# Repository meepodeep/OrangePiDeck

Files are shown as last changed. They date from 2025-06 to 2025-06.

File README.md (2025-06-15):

# ModuDeck





## A modular cyberdeck that supports multiple SBCS.
  - ### Modules
    - [Exoskeleton](##exoskeleton)
    -   [Compute Modules](##compute) 
        - [Pi 5](###pi-5)
        - [Pi zero 2 w](###pi-zero-2-w)
        - [Lattepanda Mu](###lattepanda-mu)
    - [Battery Modules](##battery)
      - [High Capacity](###2p4s)
      - [Low Capacity](###4s1p)
    - [Keyboard](##keyboard)
    - [Display](##display)
    - [How to assemble modules](##final-assembly)
  - [BOM](#bom) 
## What is the point
I set out to make a modular cyberdeck because I wanted to try to design something that doesnt follow the modern design trends of slimmer and less upgradeable and repairable computers. The modular concept helps alleviate these problems by making use of easily replaceable and upgradeable batteries and SBCs. This also solves the problem of many custom projects being very inconvenient to do maintenance on. For example, some people hotglue everything into place, making the project nearly impossible to work on. In this project, however, every part that you would need to replace is easily replaceable with m3 and m2.5 hardware, securing it in place. 

# Assembly Instructions
- ## Exoskeleton
  - ### Printing
1. Print Both main case peices vertically
2. Print both rear cases flat or vertically if you have elephants foot issues
3. Assemble both sides of each part together using either superglue, plastic welding, or your preferred method of attaching 3d prints.
4. Use m3 hardware to secure the back on once done with wiring exept leave these 3 holes unscrewed, they are for mounting the modules.
5. 
6. 

  - ### Wiring
1. Press fit all of the connectors including, HDMI, XT60, and the magnetic 4pin adafruit connector.
   
   
   
   
  
3. Solder the 12v supply for the xt60 on the battery to the 12v supply on the compute xt60 with 18awg wire.
4. Solder the 5v supply for the xt60 on the battery to the 5v supply on the compute xt60 with 18awg wire.
   
   
   
   
- ## Compute
  - ### Pi 5
 
  
  
1. Print the pi 5 compute model.
2. Assemble the cooler.
3. Solder 28awg wire to the 4 USB pins from the Bottom of the USB 2.0 connector on the set of pins closest to the edge of the board.
4. Remove the casing from the micro HDMI to HDMI adapter.
5. Press the HDMI into the casing.
6. Solder the 5v and gnd connections from the gpio to the + and - terminals onto an xt60 connector using 18awg wire. Press the connector into the 5v part of the module.

  Raspberry-Pi-5-Pinout--1
  
7. Press the 5v Xt60 into the case.
8. Solder the other ends of the wires coming from the USB to the magnetic connector in this order, from left to right, on the pin side. Ground, Data+, Data-, Vcc.
9. Press the Magnetic connector into the case.
10. Screw the pi into the mounting posts with m2.5 hardware.
  - ### Pi zero 2 w



1. Print the Pi Zero Compute model.
2. Assemble the cooler
3. Decase the USB hub.
4. Solder 28awg wire to the pins of the USB port at the end of the hub.
5. Solder the other ends of the wires coming from the USB to the magnetic connector in this order, from left to right, on the pin side. Ground, Data+, Data-, Vcc.
6. Press the Magnetic connector into the case.
7. Solder the 5V and GND connections from the GPIO to the + and - terminals onto an xt60 connector using 18awg wire.
8. Press the connector into the 5V part of the module.

j8header-zero

9. Decase the mini HDMI adapter on the big HDMI side.
10. Press the HDMI into the case, and plug in the mini HDMI.
11. Screw the pi into the mounting posts with m2.5 hardware.
  - ### Lattepanda mu
1. Print the Lattepanda compute module.
2. Assemble the Panda, cooler, and devboard.
3. Desolder the Barrel jack connector
5. Solder 28awg wire to the 4 USB pins on the bottom of the furthest USB connector from the edge of the board on the port that is covered by the case.



6. Solder 18awg wire to the + and - of the barrel jack and solder them to the + and - of an xt60.
7. Press that into the 12V supply port on the module.
8. Solder the other ends of the wires coming from the USB to the magnetic connector in this order, from left to right, on the pin side. Ground, Data+, Data-, Vcc.
9. Desolder the hdmi port and solder 28awg magnet wire or normal wire onto each pin (i know its annoying) and also to the corresponding pins on the board, make these wires long enough to reach the other side of the case.
10. Press the HDMI port into the case.

- ## Battery
  - ### Build
1. Print battery module cover.
2. Print battery module.
  - ### 2p4s
    - Wiring
- # BEFORE DOING THIS MAKE SURE ALL OF THE CELLS ARE AT THE SAME VOLTAGE SO YOU DONT EXPLODE YOU HOUSE!!
1.  Wire 4 pairs of cells in a 1p configuration by spot welding nickel strips in between the cells.
2.  
3.  Wire all 4 of those 1p cells in series into a 2p4s Configuration by spot welding nickel strips, this is the green section of the diagram.
4.  Solder 5 equal-length wires of 22awg to the BMS and to the parts of the battery; these are the purple wires in the diagram.
5. 
6.  Solder a 12awg wire to the - terminal on the BMS.
7.  Solder a 12awg wire to the + terminal on the BMS and to the power switch, solder another 12awg wire to the other side of said switch, and press it into the case.
8.  
9.  Follow the wiring diagram from step 8 in order to complete the battery, then make sure to insulate all of the connections with your preferred method.
10.  Press both XT60s into their respective ports.
11.  Screw on the top using m3 hardware.
  - ### 4s1p
    - Same as 2p4s, but instead of having cell pairs, just use individual cells. 
- ## Keyboard
- 

1. Solder all of the switches onto the PCB.
2. Solder all of the diodes onto the PCB.
4. Solder the Pi Pico onto the bottom of the PCB.
5. Use [QMK Configurator](https://docs.qmk.fm/configurator_step_by_step) to configure and flash the board [here](https://config.qmk.fm/#/rart/rart75hs/LAYOUT_ansi_split_bs)
6.  Desolder the pi picos usb port.
7. Solder a 28awg wire onto each of the usb pads.
8. Solder the other ends of the wires coming from the USB to the magnetic connector in this order, from left to right, on the pin side vcc, Data-, Data+, Ground.
9. Press the magnetic connector into its slot where the compute module clips in.
10. 
11. Slide the keyboard in and screw it down using m3 hardware.
- ## Display
1. Print both screen mount halves and secure them together using ca plastic welding or your preferred adhesive.
2. Use double-sided tape to secure the driver board to the back of the screen on the left side, away from the compute module.
3. Position the screen in the main case and put the scren mount around it aligned with the screw holes.
4. Screw in m3 hardware from the top of the case in all of the holes.
5. Plug the HDMI coming from the compute module bay into the display board.
6. Use 18awg wire to the 12V XT60 from the battery module bay to the power pads on the driver board after desoldering the barrel plug.
- ## Final Assembly
1. Slot the compute module into the left of the cyberdeck making sure all of the connectors line up.
2. Use 2 m3 bolts to secure the module in place.
3. 
4. Slot the battery in, turned off, into the slot on the right, making sure all of the connectors line up.
5. Screw in one m3 bolt to secure it in place
6. 

# BOM

| Item |	Quantity |	Total price+Shipping | Use In project	| Item Source
| --- | --- | --- | --- |--- |
| General |||||			
| Display |	x1 |	$64.19 |	displays | https://www.ebay.com/itm/145841358470? |
| m3 hardware kit |	x1	| $7.99|	Mount most things	| https://www.amazon.com/Hincell-540pcs-Button-Washers-Stainless/dp/B0D1CV8V9Y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|
|m2.5 4mm |	x1 |	$1.86 |	mount the pis if you use them |	https://www.aliexpress.us/item/3256805692588351.html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|
|18awg wire	| x1 |	$13.76 | most wiring |	https://www.amazon.com/Nilight-Electrical-Conductor-Extension-Amplifier/dp/B0CYZPW42Q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 |
|28awg wire	| x1 |	$7.99 |	Usb wiring |	https://www.amazon.com/Fermerry-Stranded-Silicone-Cables-Electrical/dp/B089CR4SDM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 |
|12awg wire |	x1 |	$3.94 |	Battery wires |	https://www.aliexpress.us/item/3256807129117447.html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|
|Filament	| x1 |	$20 |	be every printed part |	Idk wherever you get filament |
|xt60s	| x1 |	$8.99 |	be every printed part |	[amazon](https://www.amazon.com/Amass-Bullet-Connector-Upgrated-Sheath/dp/B074PN6N4K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) |
|Magnetic Connectors| x1 | $$3.67 | Connect usb |https://www.aliexpress.us/item/3256805098127227.html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|
|Nickel strip| x1| $5.69 | build batteries| https://www.amazon.com/MECCANIXITY-Nickel-Battery-Soldering-Welding/dp/B0CVXLLGCQ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|
|Total|| $138.08 |||
||||||
|Keyboard Parts	| | | | |	
|Pi pico |	x1 |	$4 |	drive the keyboard | https://www.adafruit.com/product/4864 |
|Keyboard pcb	| x5 |	$35.47 |	Be a keyboard PCB |	PCBWAY |
|Gateron Red	| x100	| $34.40 |	Be switches |	https://www.aliexpress.us/item/3256805905674117 |
|Keycaps |	x80 |	$14.16 |	Be keycaps |	https://www.aliexpress.us/item/3256807292808339.html? |
|Shipping |	$6.99	| | | |
|Total | |$95 | | |		
||||||
|Battery Module 2p4s |||||				
|DC-DC converter |	x2 |	$25.60 |	Convert the battery voltage to 12v/5v |	https://www.dfrobot.com/product-2599.html |
|18650s | x8 |	$29.28 |	be batteries |	https://www.18650batterystore.com/products/samsung-25r-18650?variant=37119890063511 |
|Bms |	x1 |	$1.75 |	be a bms for the batteries |	https://www.aliexpress.us/item/ |
|RA11131121 |	x1 |	$0.69 |	power switch |	https://www.mouser.com/ProductDetail/E-Switch/RA11131121?qs=QtyuwXswaQhes8SRTBHYHQ%3D%3D&mgh=1&gQT=1 |
|373 |	x1 |	$0.95 |	charger |	https://www.mouser.com/ProductDetail/Adafruit/373?qs=GURawfaeGuDDC%2FyE6Usrdw%3D%3D |
|Total| |	$58.27 | | |	
|Battery Module 4s1p |||||	
|DC-DC converter |	x2 |	$25.60 |	Convert the battery voltage to 12v/5v |	https://www.dfrobot.com/product-2599.html |
|18650s | 	x4 |	$18.59 |	be batteries |	https://www.18650batterystore.com/products/samsung-25r-18650?variant=37119890063511 |
|Bms |	x1 |	$1.75 |	be a bms for the batteries |	https://www.aliexpress.us/item/ |
|RA11131121 |	x1 |	$3.26 |	power switch |	https://www.aliexpress.us/item/3256808591861621.html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 |
|Total | | $49.20 |	| |	
||||||
|Pi zero 2 w compute | | | | |
|pi zero 2 w	| x1 |	$23.00 |	Main computer |	https://www.adafruit.com/product/5291 |
|mini hdmi to hdmi adapter |	x1 |	$6.99 |	adapt the HDMI |	https://www.amazon.com/Micro-Adapter-Female-Support-Raspberry/dp/B09HS74STL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 |
| USB hub and pi cooloer	| x1 |	$9.99 |	Cool the pi and breakout usb |	https://www.amazon.com/Raspberry-iUniker-Aluminum-Passive-Adapter/dp/B09XK36QNB/140-2177712-4060064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 |
|Total |	| $39.98 |	| | |	
||||||	
|Pi 5 Compute | | | | |
|Pi 5 8gb |	x1 |	$96.98 |	main computer |	https://www.pishop.us/product/raspberry-pi-5-8gb/?searchid=0&search_query=pi+5|
|Micro HDMI to Standard HDMI |	x1 |	$4.25 |	hdmi adapter |	https://www.pishop.us/product/micro-hdmi-to-standard-hdmi-adapter-white/|
|Cooler	| x1 |	$8.95 |	cool the pi |	https://www.pishop.us/product/dedicated-all-in-one-aluminum-cooler-for-raspberry-pi-5-pwm/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|
|Total | | $110.18 | | |	
||||||
|Lattepanda Mu Compute| | | | |	
|Lattepanda Mu with lite carrier and active cooler |	x1 |	$220.00 |	main computer |	https://www.dfrobot.com/kit-004.html|
|Total| |	$220.00| | |

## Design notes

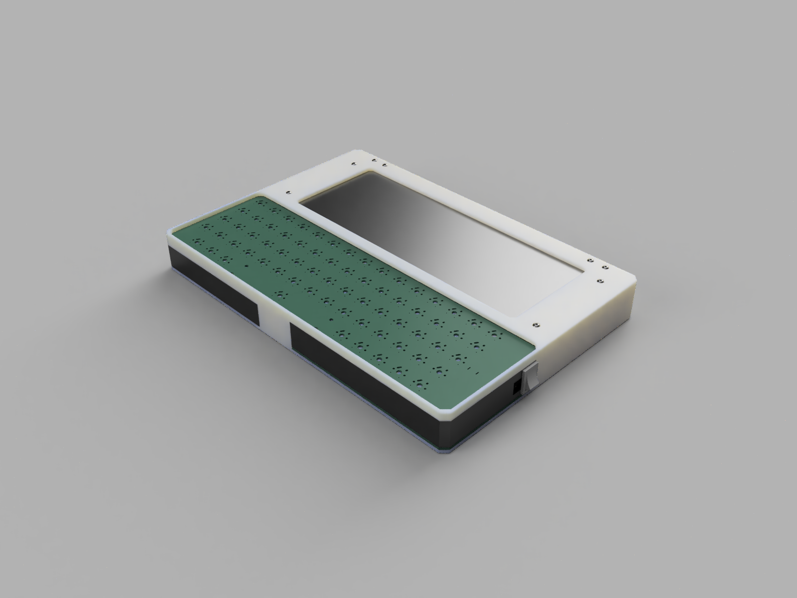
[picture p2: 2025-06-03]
OrangeDeck_Keyboard_2025-Jun-01_12-19-17AM-000_CustomizedView39958334056.png

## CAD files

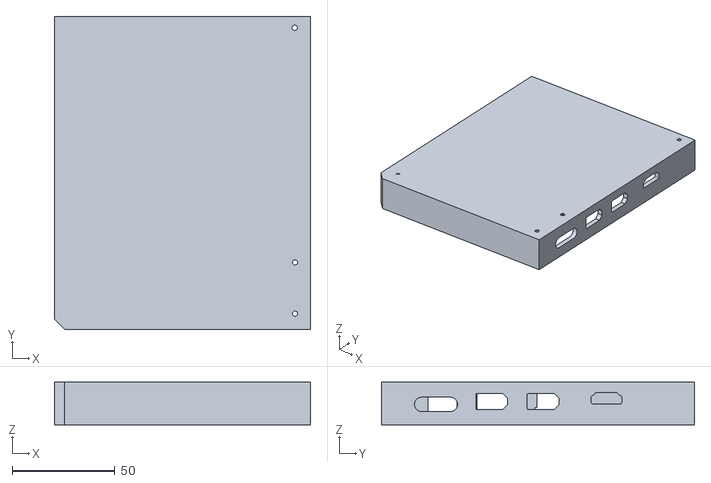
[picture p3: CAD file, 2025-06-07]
Panda Compute Main.stl
124.8 x 152.4 x 20.8

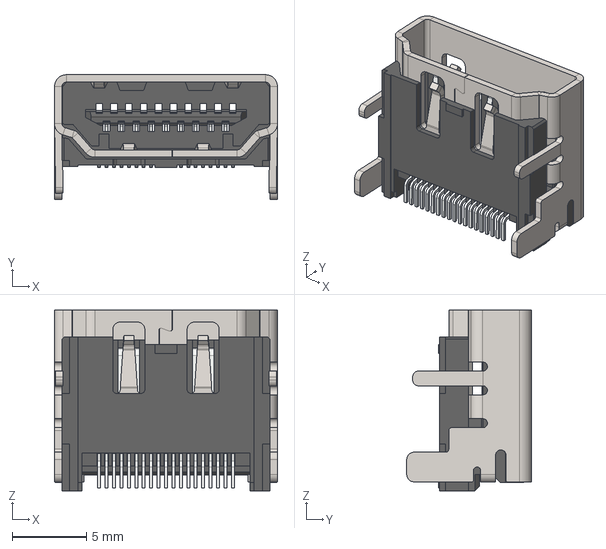
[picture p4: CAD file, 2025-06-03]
Component Steps/molex.STEP
15.0 x 8.38 x 12.1 mm

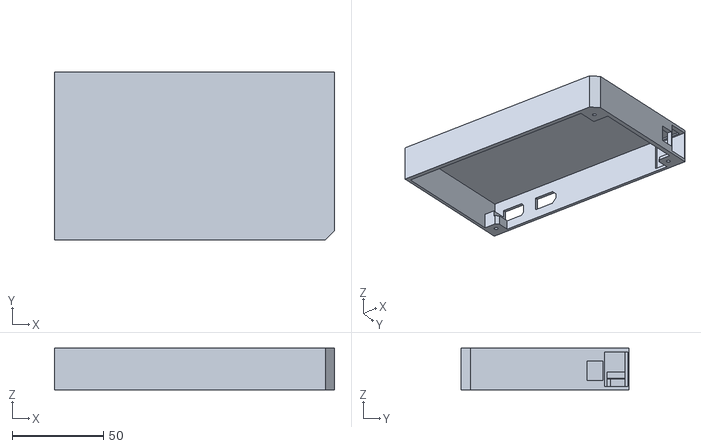
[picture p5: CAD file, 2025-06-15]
Final Print files/Battery/Battery module.stl
153.6 x 92.0 x 22.9

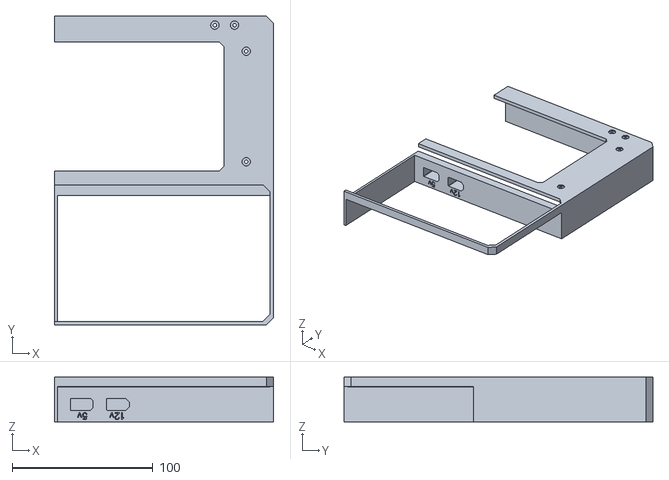
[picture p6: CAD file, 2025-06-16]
Final Print files/Exoskeleton/Case Right.stl
155.8 x 219.6 x 32.0

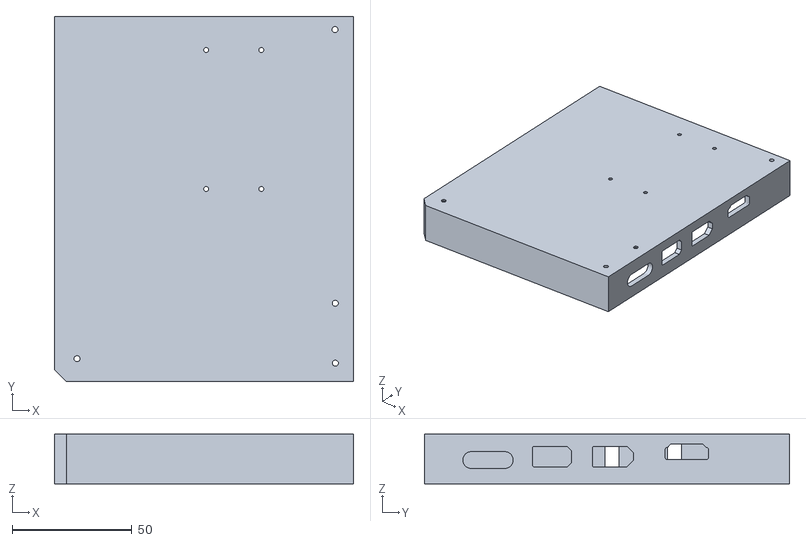
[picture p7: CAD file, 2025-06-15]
Final Print files/Pi compute/Rpi zero compute.stl
124.8 x 152.4 x 20.8

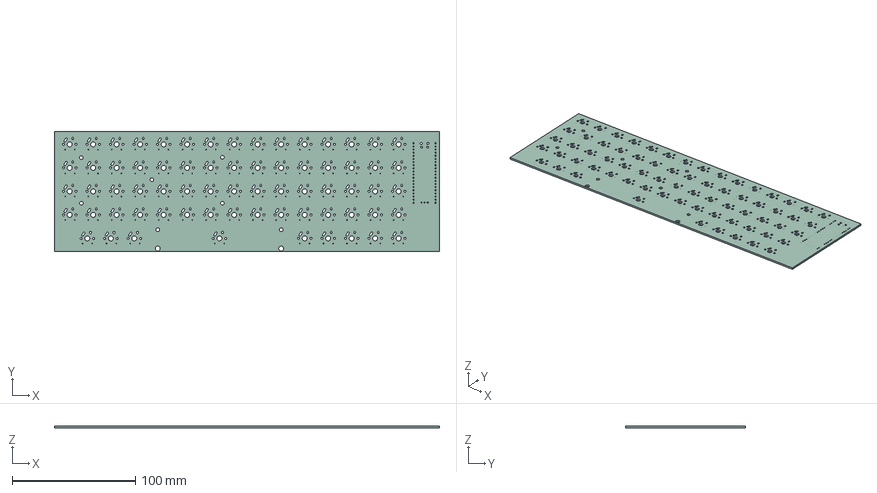
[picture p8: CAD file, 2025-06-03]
ModuDeck Keyboard/ModuDeck Keyboard.step
312.1 x 97.1 x 1.51 mm

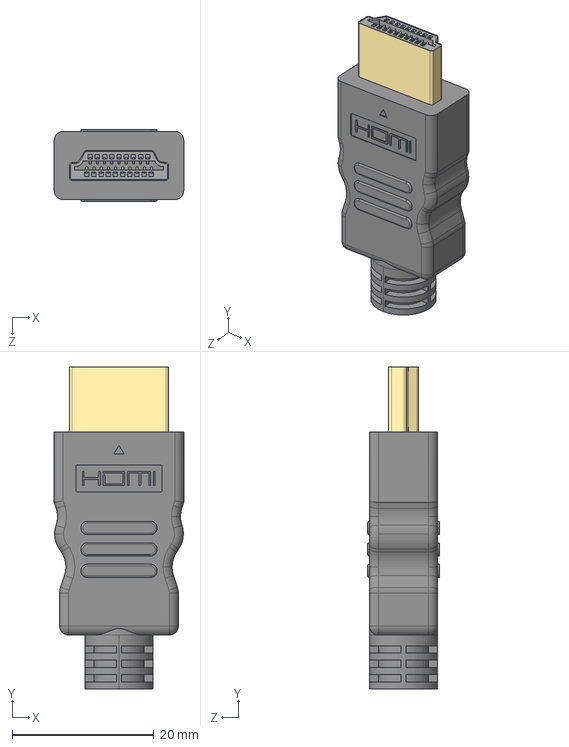
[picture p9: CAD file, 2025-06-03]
Component Steps/HDMI Male V2.STEP
18.3 x 45.5 x 10.2 mm

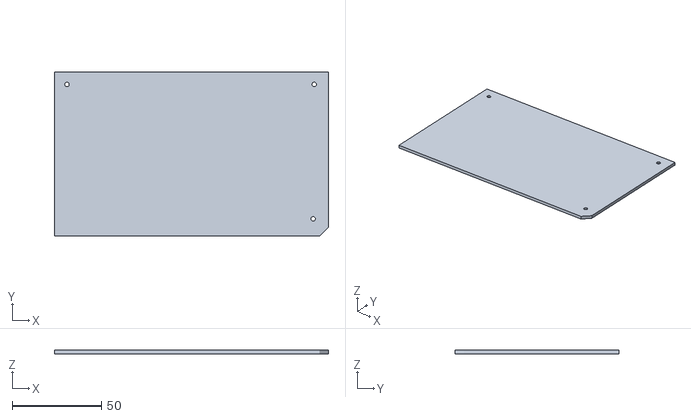
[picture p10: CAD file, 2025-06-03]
Final Print files/Battery/Battery module cover.stl
153.6 x 92.0 x 1.99

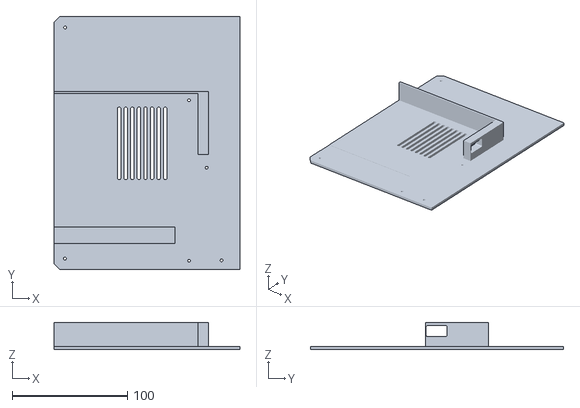
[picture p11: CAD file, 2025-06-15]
Final Print files/Exoskeleton/Back Case left.stl
161.3 x 219.6 x 23.8

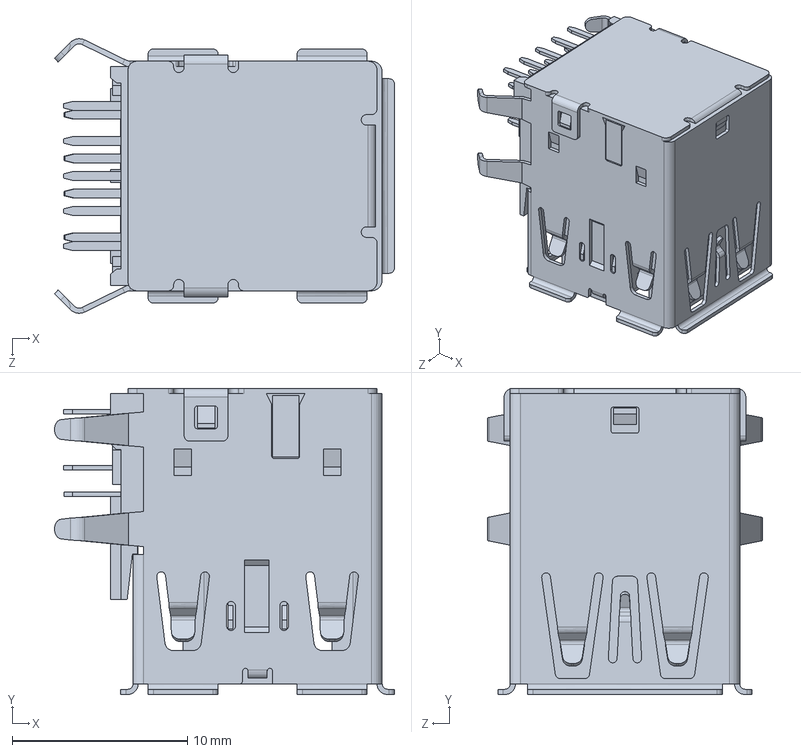
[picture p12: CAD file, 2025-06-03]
ModuDeck Keyboard/usb3x2.SLDPRT
19.4 x 17.5 x 15.7 mm

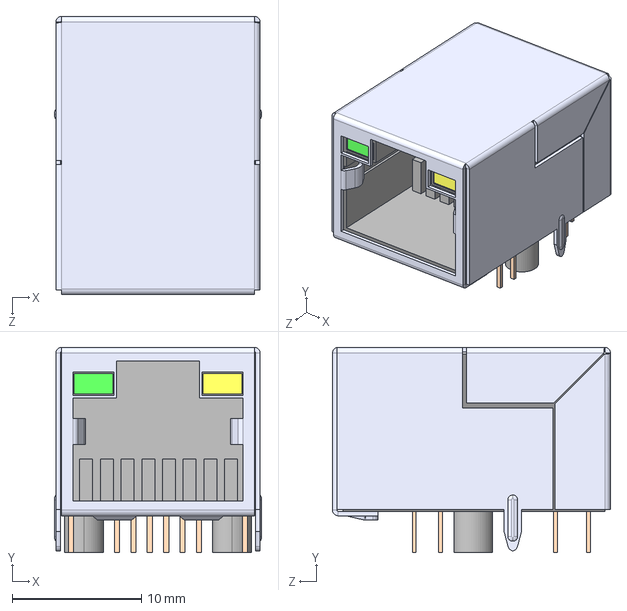
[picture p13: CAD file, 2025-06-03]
Component Steps/RJ45_10P_TJ3009.STEP
16.0 x 15.9 x 21.5 mm

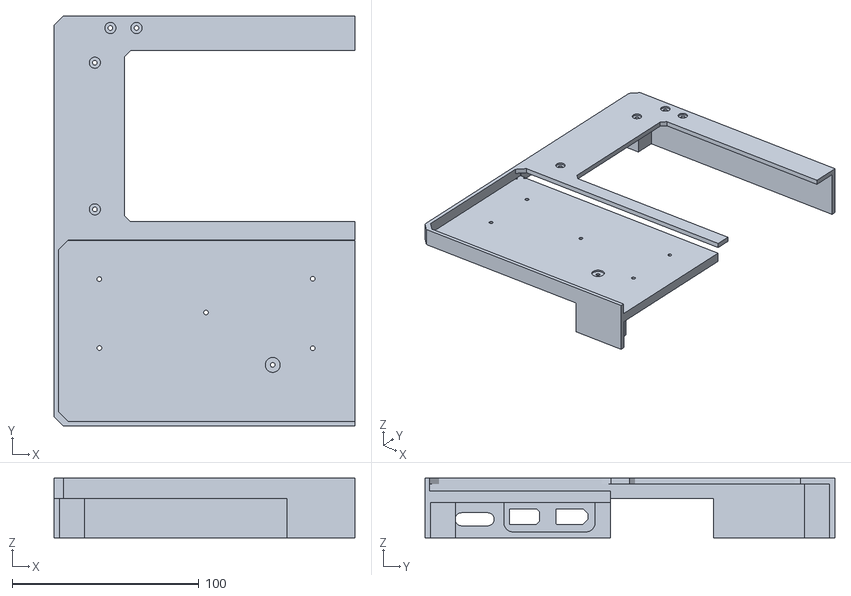
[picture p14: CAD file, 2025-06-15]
Final Print files/Exoskeleton/Case left.stl
161.3 x 219.6 x 32.0

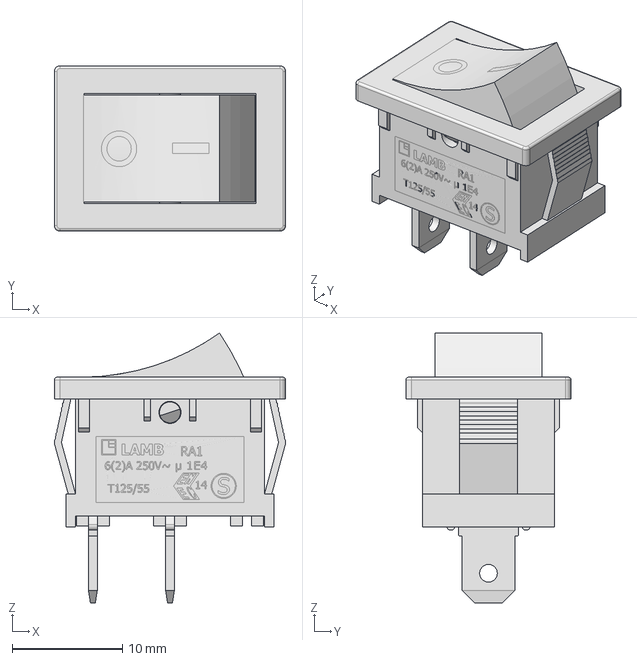
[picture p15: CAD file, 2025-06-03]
Component Steps/RA1113xxx1.stp
21.0 x 15.0 x 24.5 mm

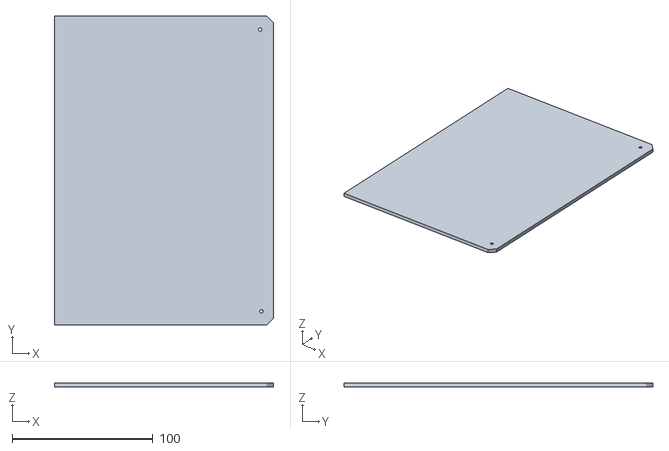
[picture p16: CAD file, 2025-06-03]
Final Print files/Exoskeleton/Back Case right.stl
155.8 x 219.6 x 3.00

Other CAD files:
Final Print files/Compute Module Template.step
Final Print files/Pi compute/Pi 5 Compute.stl
Component Steps/XT60_Hembra.STEP
Final Print files/Exoskeleton/Screen Mount other half.stl
Component Steps/Case.3mf
Component Steps/DC Power Jack 5.5mm x 2.1mm.STEP
Component Steps/Screen Mount.3mf
Component Steps/USB Type C Port (SMD Type).STEP
Component Steps/connecteurmagnetique.STEP
Final Print files/Exoskeleton/Back case.stl
Final Print files/Exoskeleton/Case.stl
Final Print files/Exoskeleton/Screen Mount.stl

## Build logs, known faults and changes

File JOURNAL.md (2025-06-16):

---
title: "ModuDeck"
author: "Meepodeep"
description: "Cyberdeck but Modular!"
created_at: "2025-05-22"
---
# Total time spent ~52 hours, (I think I forgot to log a few days and I dont remember what days 😢)
# 5/22/25: Starting project

I started and finished the keyboard pcb design!





**Total time spent: 9h**
# 5/25/25: Worked on case.

Started making the case for the cyberdeck and also researched carrier board options. 



**Total time spent: 6h**

# 5/26/25: Worked on case.

Started designing mounts for the components in the case. 



**Total time spent: 2h**

# 5/27/25: Tried to make some sort of BOM.

I have been looking for parts for a while now. After making the Bom realized I'm going to have to sacrifice some features to stay in budget. I might try to integrate an old keyboard that I have instead of using the custom PCB I designed. Hopefully I can keep this thing under budget. 



**Total time spent: 4h**
# 5/28/25: Changed the concept entirely!

In order to stay under budget, I decided to make a modular system with you being able to hotswap SBC and battery modules in and out of the deck. I mostly just did a lot of CAD.



**Total time spent: 9h**
# 6/2/25: Finished some modules!

I finished the battery module, and i also finished the lattepanda mu module. I started work on the rpi zero module and i added some visual flairs.





**Total time spent: 3h**

# 6/3/25: Finished designing!

Today, I started doing alot of finalization steps. I made the pi 5 module, I also have a module template for both the battery and compute now. And I did alot of fine tuning of the mounts and printability of the design. After all of that, I went back and changed the keyboard to use a pi pico to make my life easier when soldering and setting up firmware. The most annoying part of today was just doing all the little touches to make this thing actually be reasonable for others and myself to assemble in real life like adding screw posts and splitting parts in half. 





**Total time spent: 7h**

# 6/4/25: started docs!

currently working on making instructions to build the project.

Check Readme.md for the progress

**Total time spent: 1h**

# 6/6/25: Worked on docs!

Wrote the assembly guide for the compute modules, batteries, and case. 

**Total time spent: 5h**

# 6/7/25: Worked on documentation and bom for every module 😢

Today I did a lot of writing. I wrote the assembly instructions for the remaining parts of the build, and i also wrote the bom with it being seperated to have individual costs for each module. 

**Total time spent: 5h**

# 6/11/25: edited some bits on the bom bc the prices changed. 

The display price changed due to going off sale, and I also ordered all the parts.

**Total time spent: 2h**

# 6/12/25: Edited the pi zero compute module

When I was test fitting something was off (i dont remember i forgot to log this day this is retroactive looking at commits) so I edited the 3d model.

**Total time spent 1h**

# 6/13/25: Edited ports.

Every port on the model was the wrong size, so nothing fit. I changed all of them to fit with measurements from the components that arrived today. Then I re printed and rebuilt it again. 

**Total time spent 5h**

# 6/14/2025 I HATE RASPBERRY PI OS!!!!

Ok so today I was just messing with linux to try to get a pi zero to do anything useful on the desktop. I have realized that this will be a command line machine until I can build a more useful compute module. I also started building stuff with the new HDMI slots and mounted the ports. 

**Total time spent 6h**

#6/15/2025 I updated all the xt60 mounts to fit the connectors.

As the title says i edited the 3d model to fit the xt60s better.

**total time spent 2h**

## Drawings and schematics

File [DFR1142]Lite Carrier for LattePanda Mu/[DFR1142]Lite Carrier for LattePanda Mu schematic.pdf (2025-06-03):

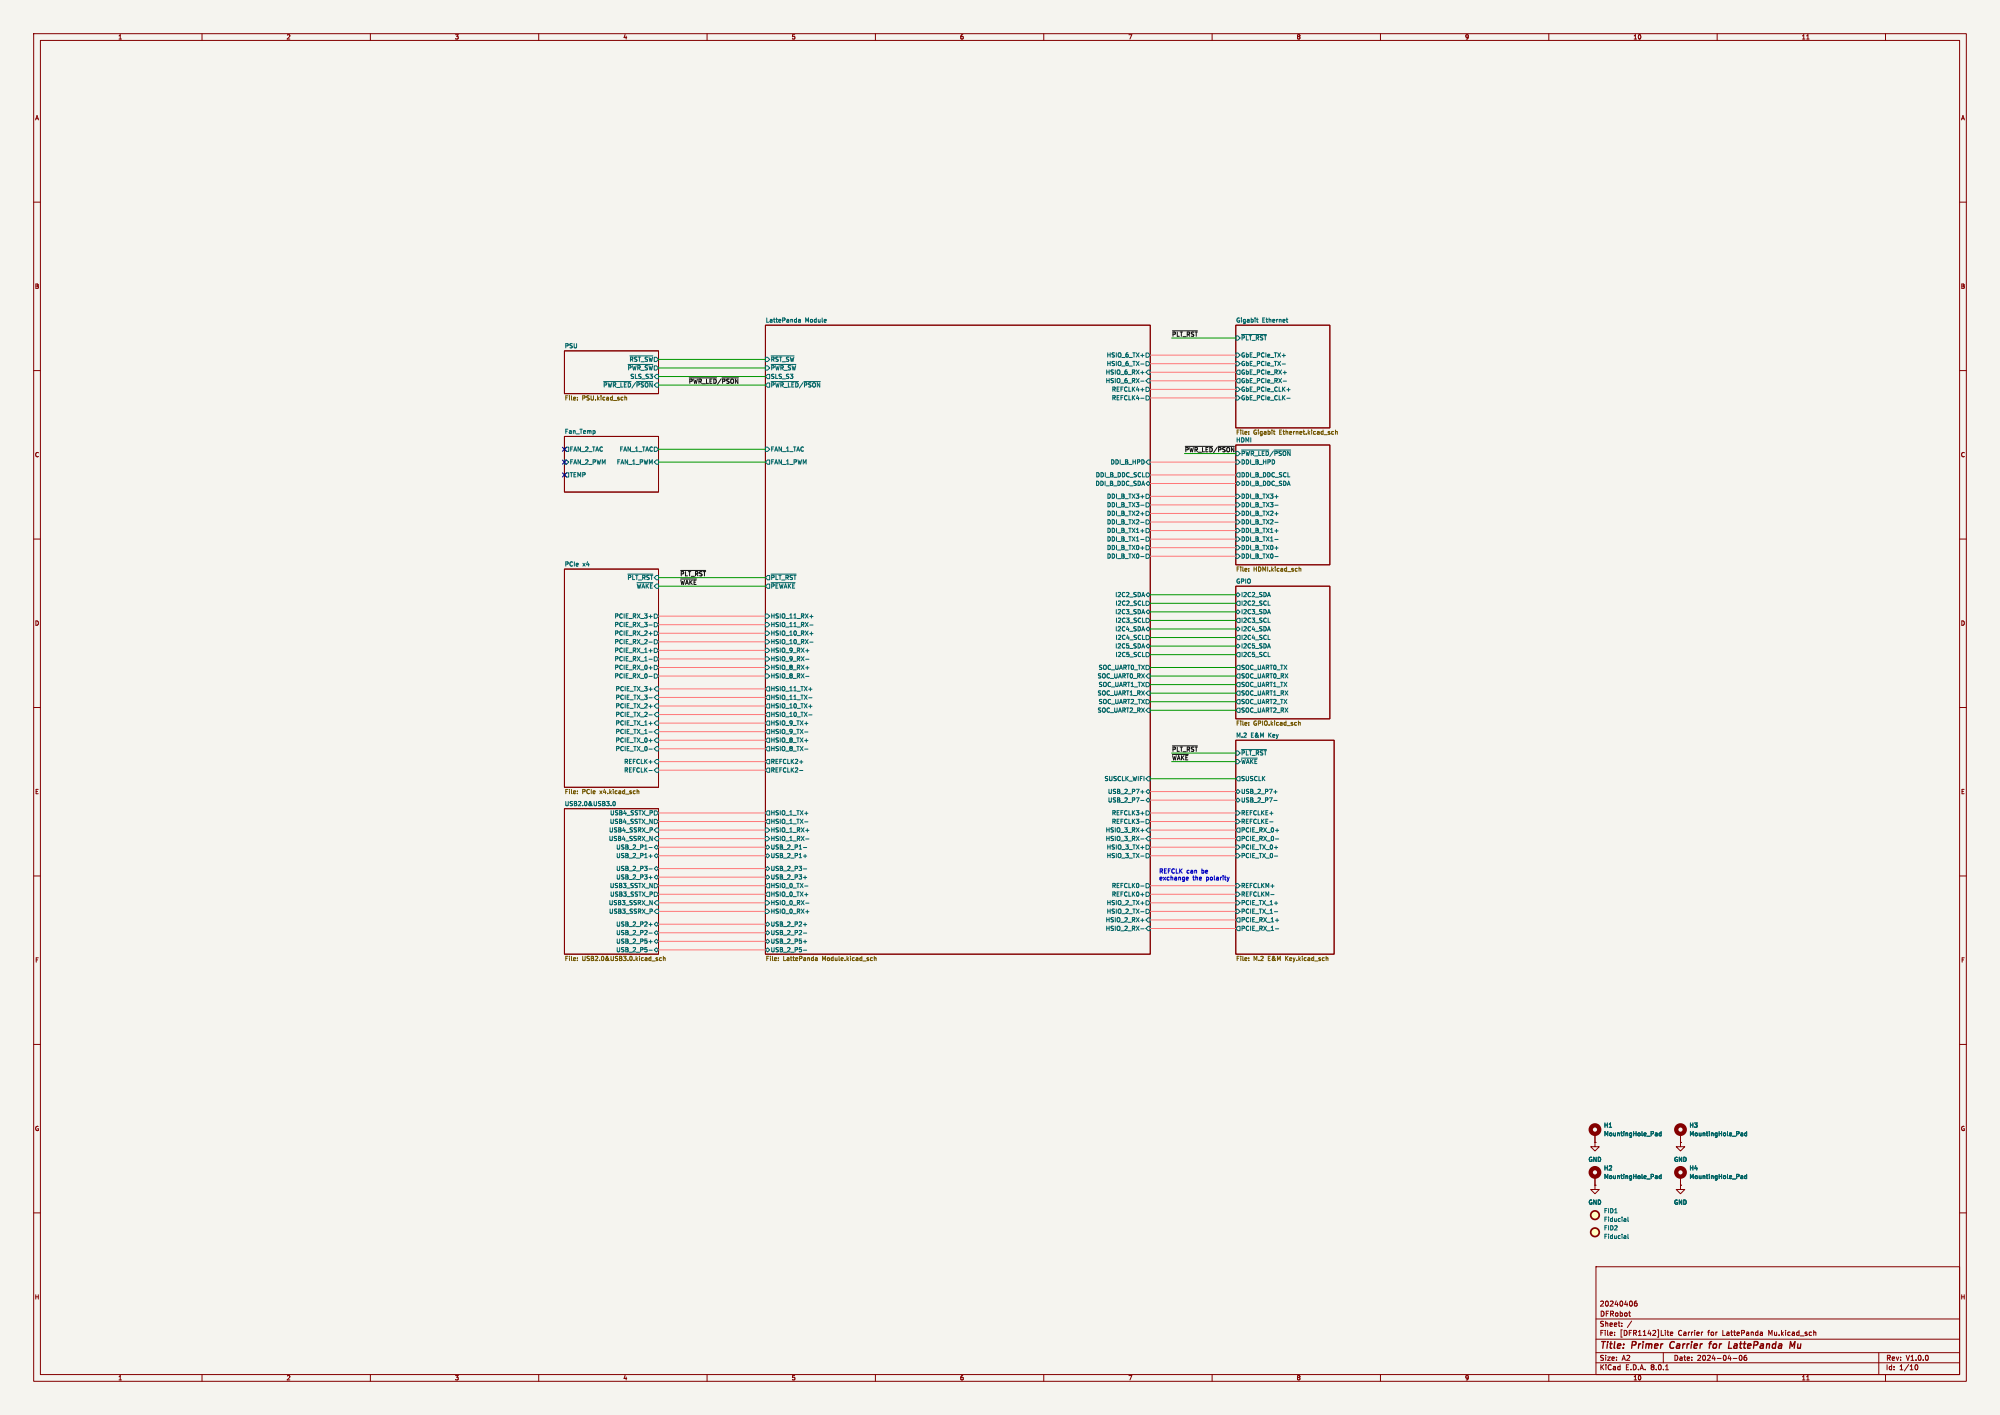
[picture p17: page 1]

Gigabit Ethernet File: Gigabit Ethernet.kicad_sch FAN_1_TAC
File: PSU.kicad_sch PCIE_RX_3- PCIE_RX_2- PCIE_RX_3+ PCIE_RX_0- PCIE_RX_1- PCIE_RX_1+ PCIE_RX_0+ PCIE_RX_2+
~{WAKE} PCIe x4 File: PCIe x4.kicad_sch USB3_SSRX_P USB3_SSRX_N
~{PLT_RST} REFCLK- REFCLK+ PCIE_TX_3- PCIE_TX_3+ PCIE_TX_2- PCIE_TX_0+ PCIE_TX_2+ PCIE_TX_1- PCIE_TX_0- PCIE_TX_1+

~{PLT_RST}
~{PWR_LED}/~{PSON} HDMI File: HDMI.kicad_sch GbE_PCIe_CLK- GbE_PCIe_RX+ GbE_PCIe_RX- GbE_PCIe_TX- GbE_PCIe_TX+ GbE_PCIe_CLK+

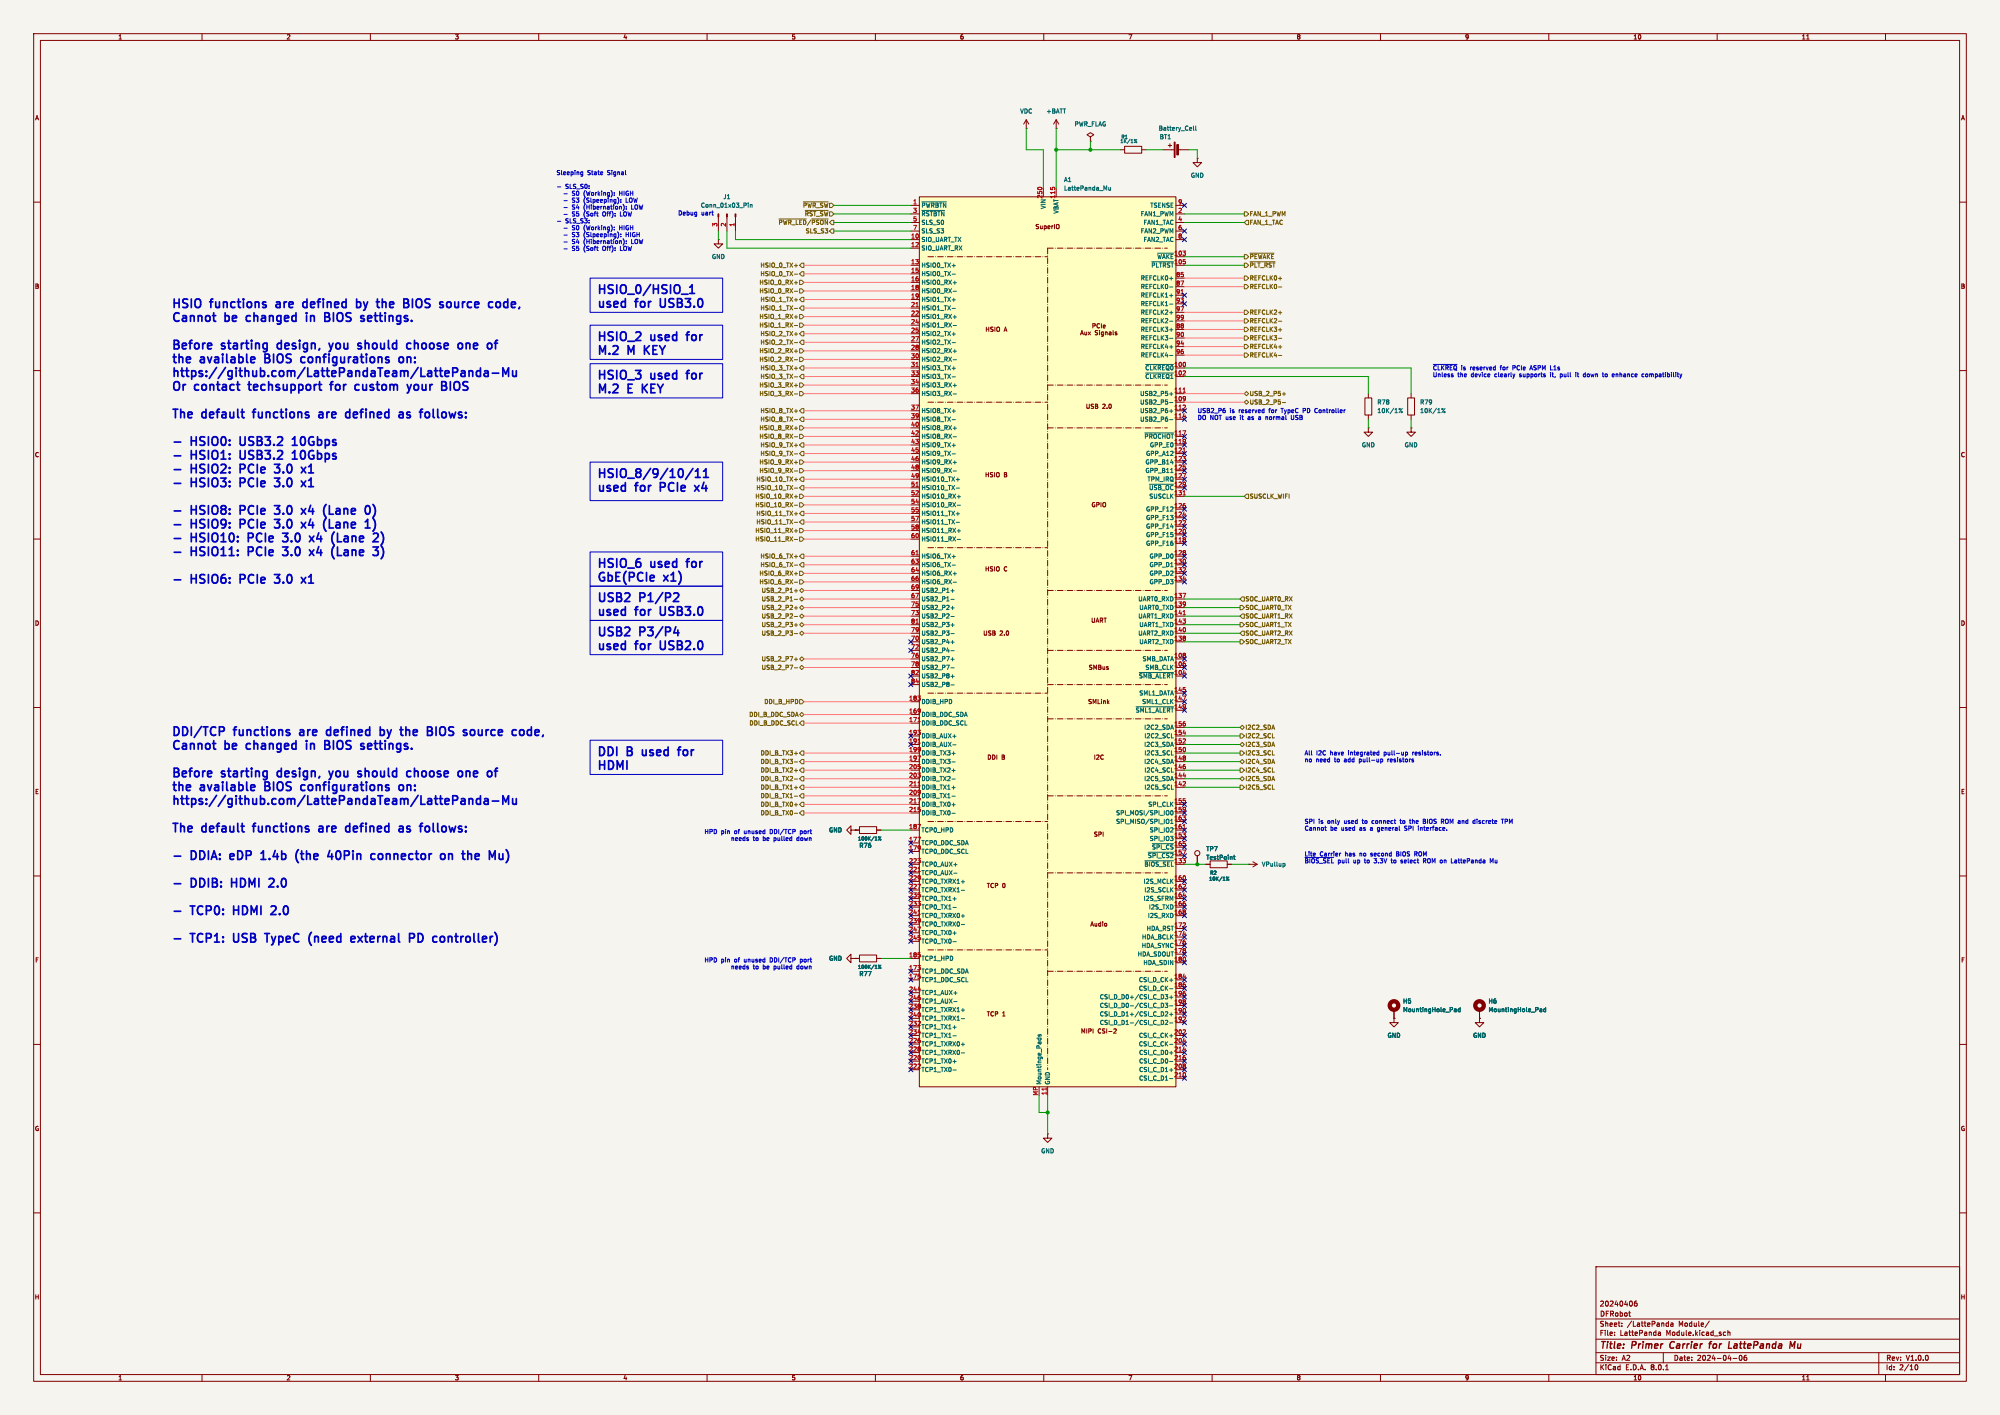
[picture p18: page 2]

- S5 (Soft Off): LOW HSIO functions are defined by the BIOS source code,

Cannot be changed in BIOS settings.

Aux Signals SMBus SMLink SPI

Before starting design, you should choose one of
https://github.com/LattePandaTeam/LattePanda-Mu
Or contact techsupport for custom your BIOS

USB2_P6 is reserved for TypeC PD Controller DO NOT use it as a normal USB HPD pin of unused DDI/TCP port needs to be pulled down DDI/TCP functions are defined by the BIOS source code,
The default functions are defined as follows:

Cannot be used as a general SPI interface. Lite Carrier has no second BIOS ROM

- DDIA: eDP 1.4b (the 40Pin connector on the Mu)

- TCP1: USB TypeC (need external PD controller)

HPD pin of unused DDI/TCP port needs to be pulled down

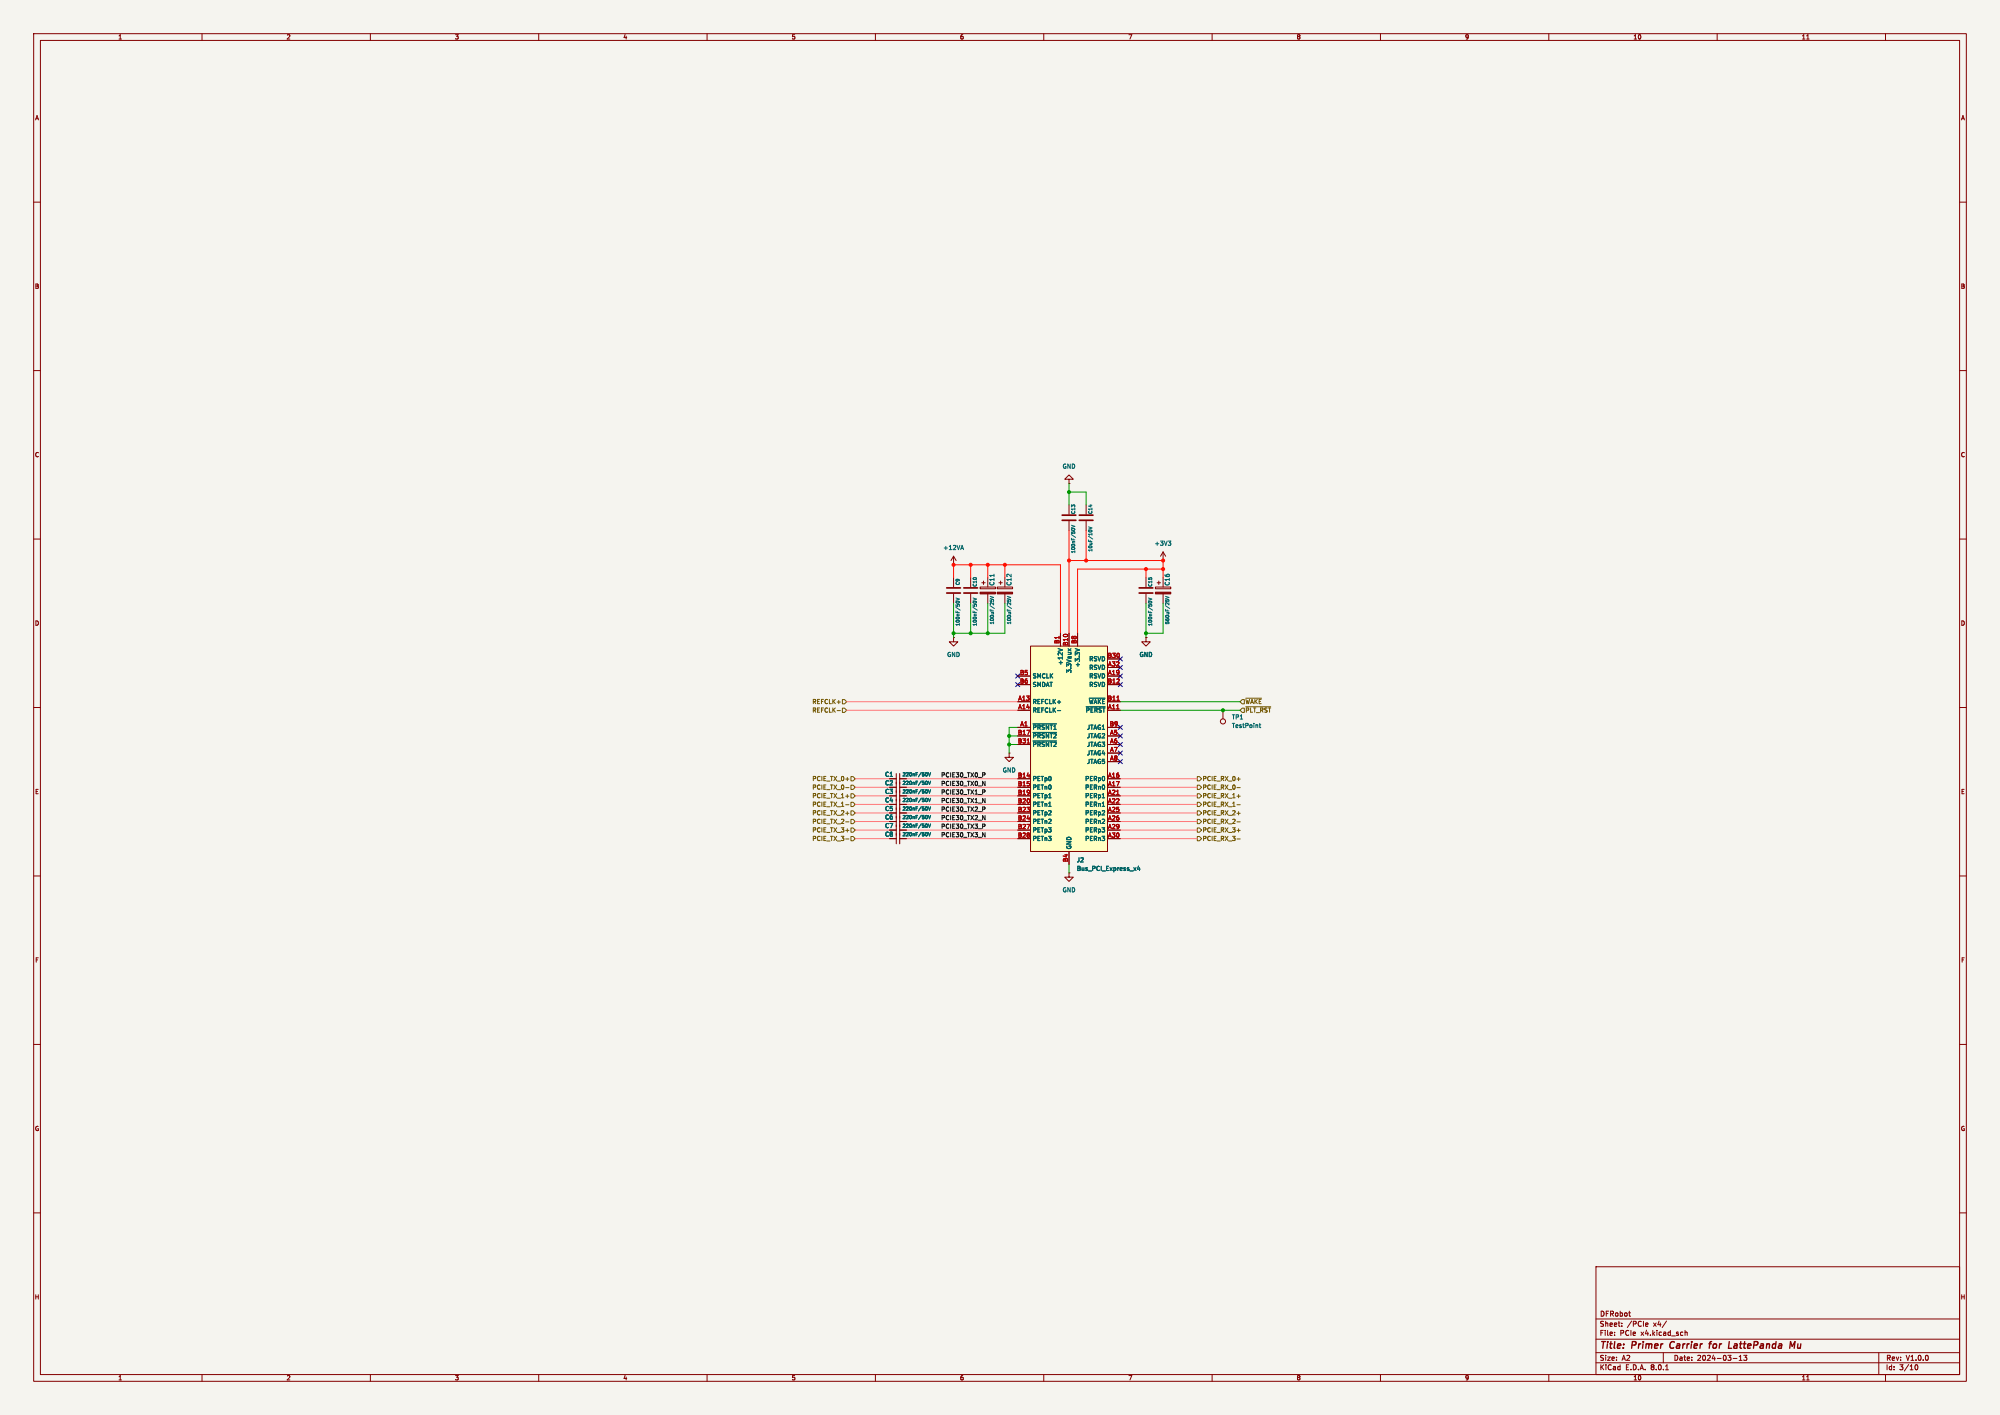
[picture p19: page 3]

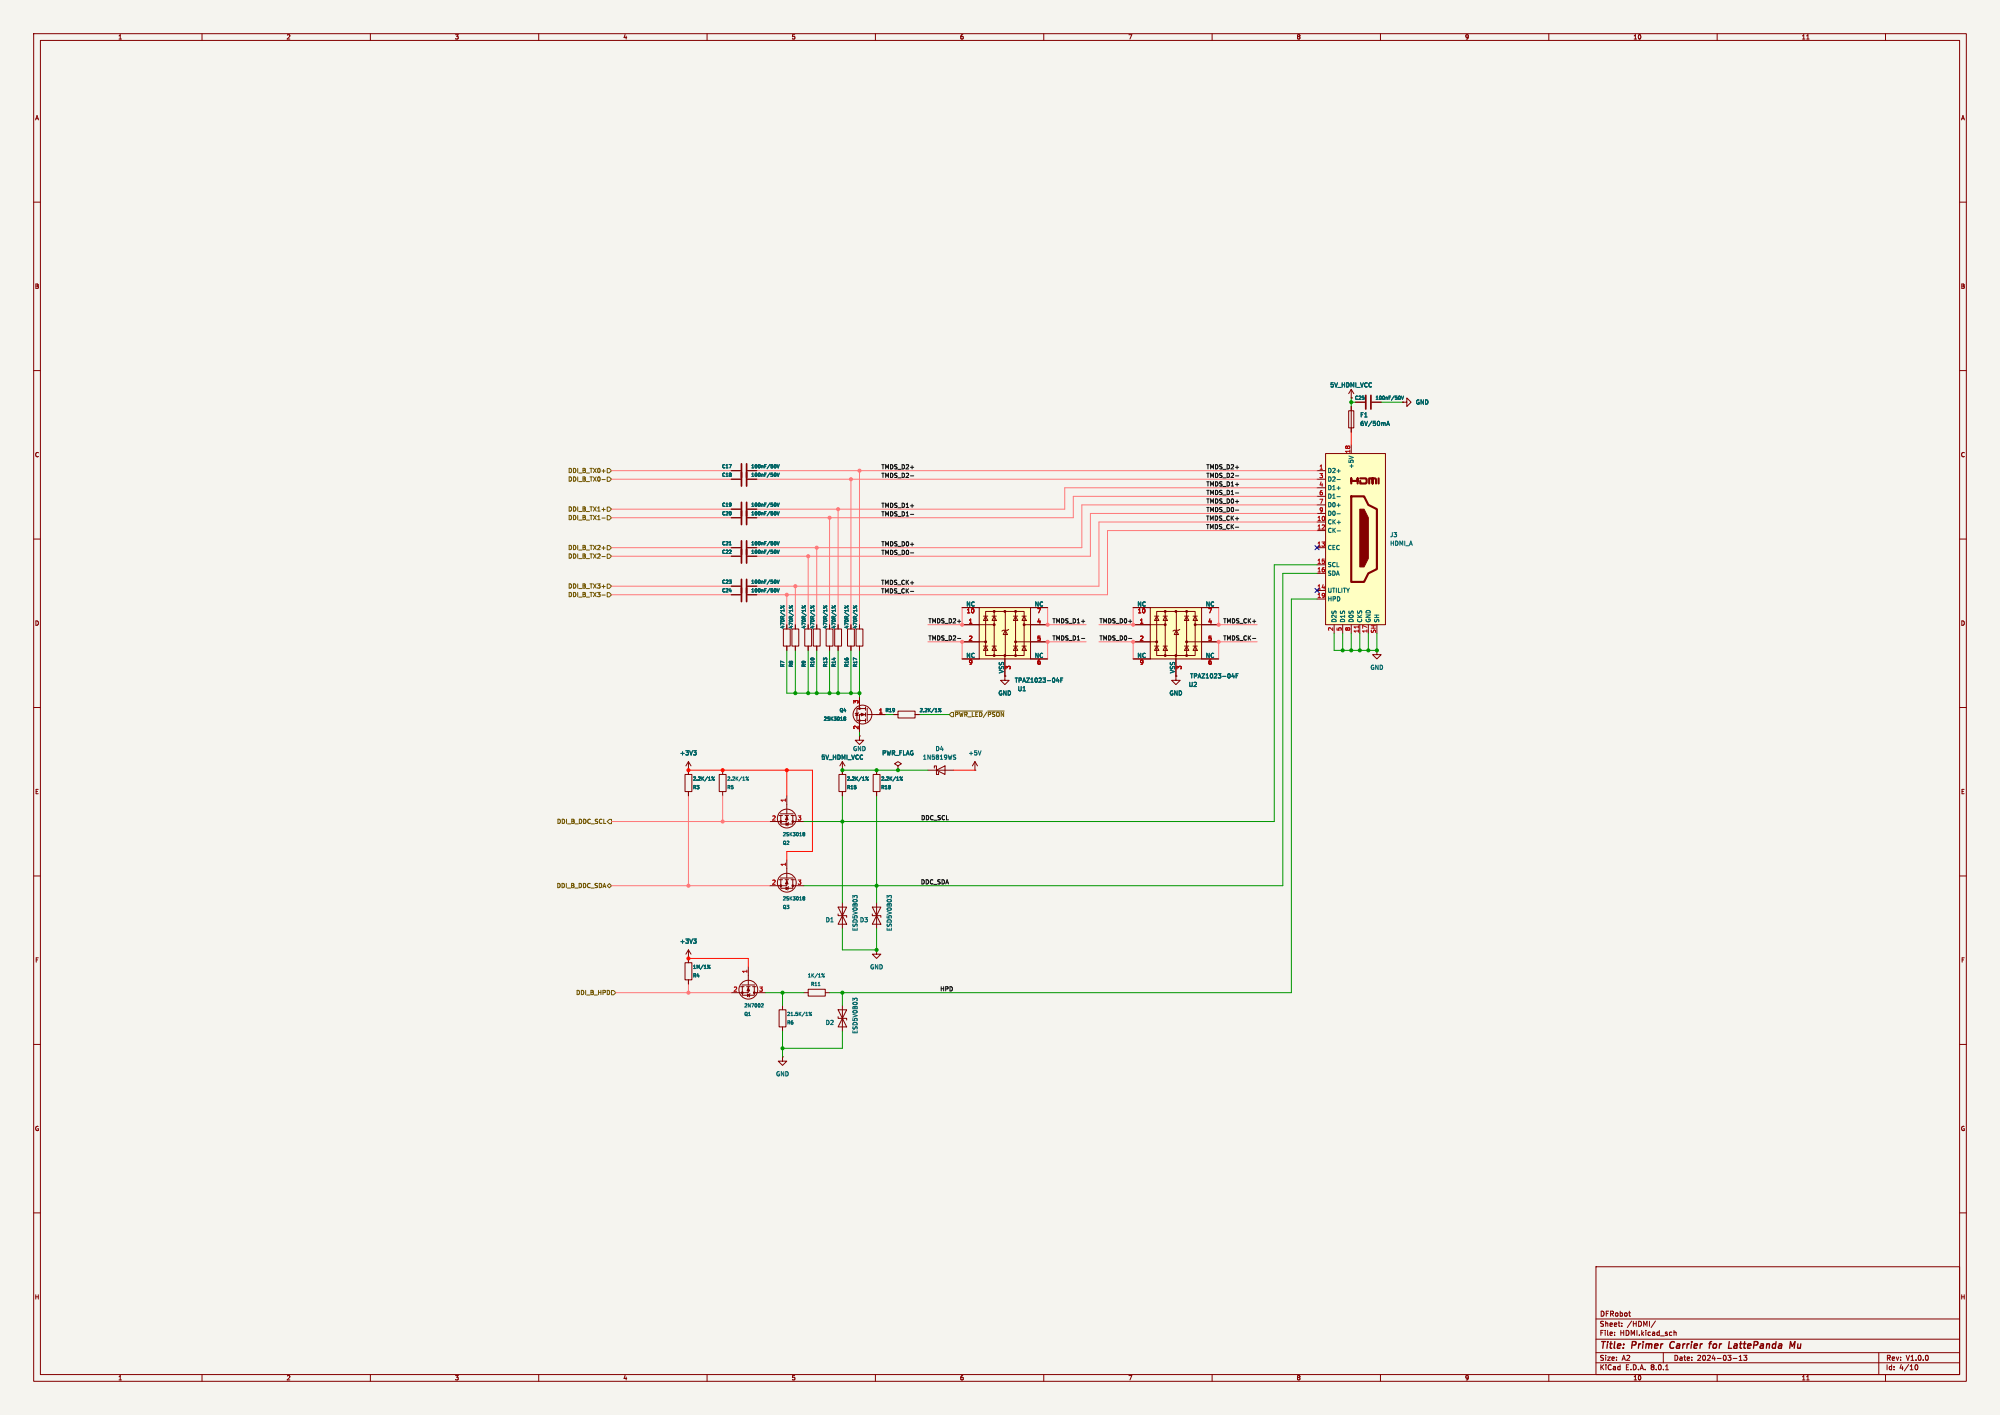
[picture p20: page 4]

File: HDMI.kicad_sch Sheet: /HDMI/ DFRobot

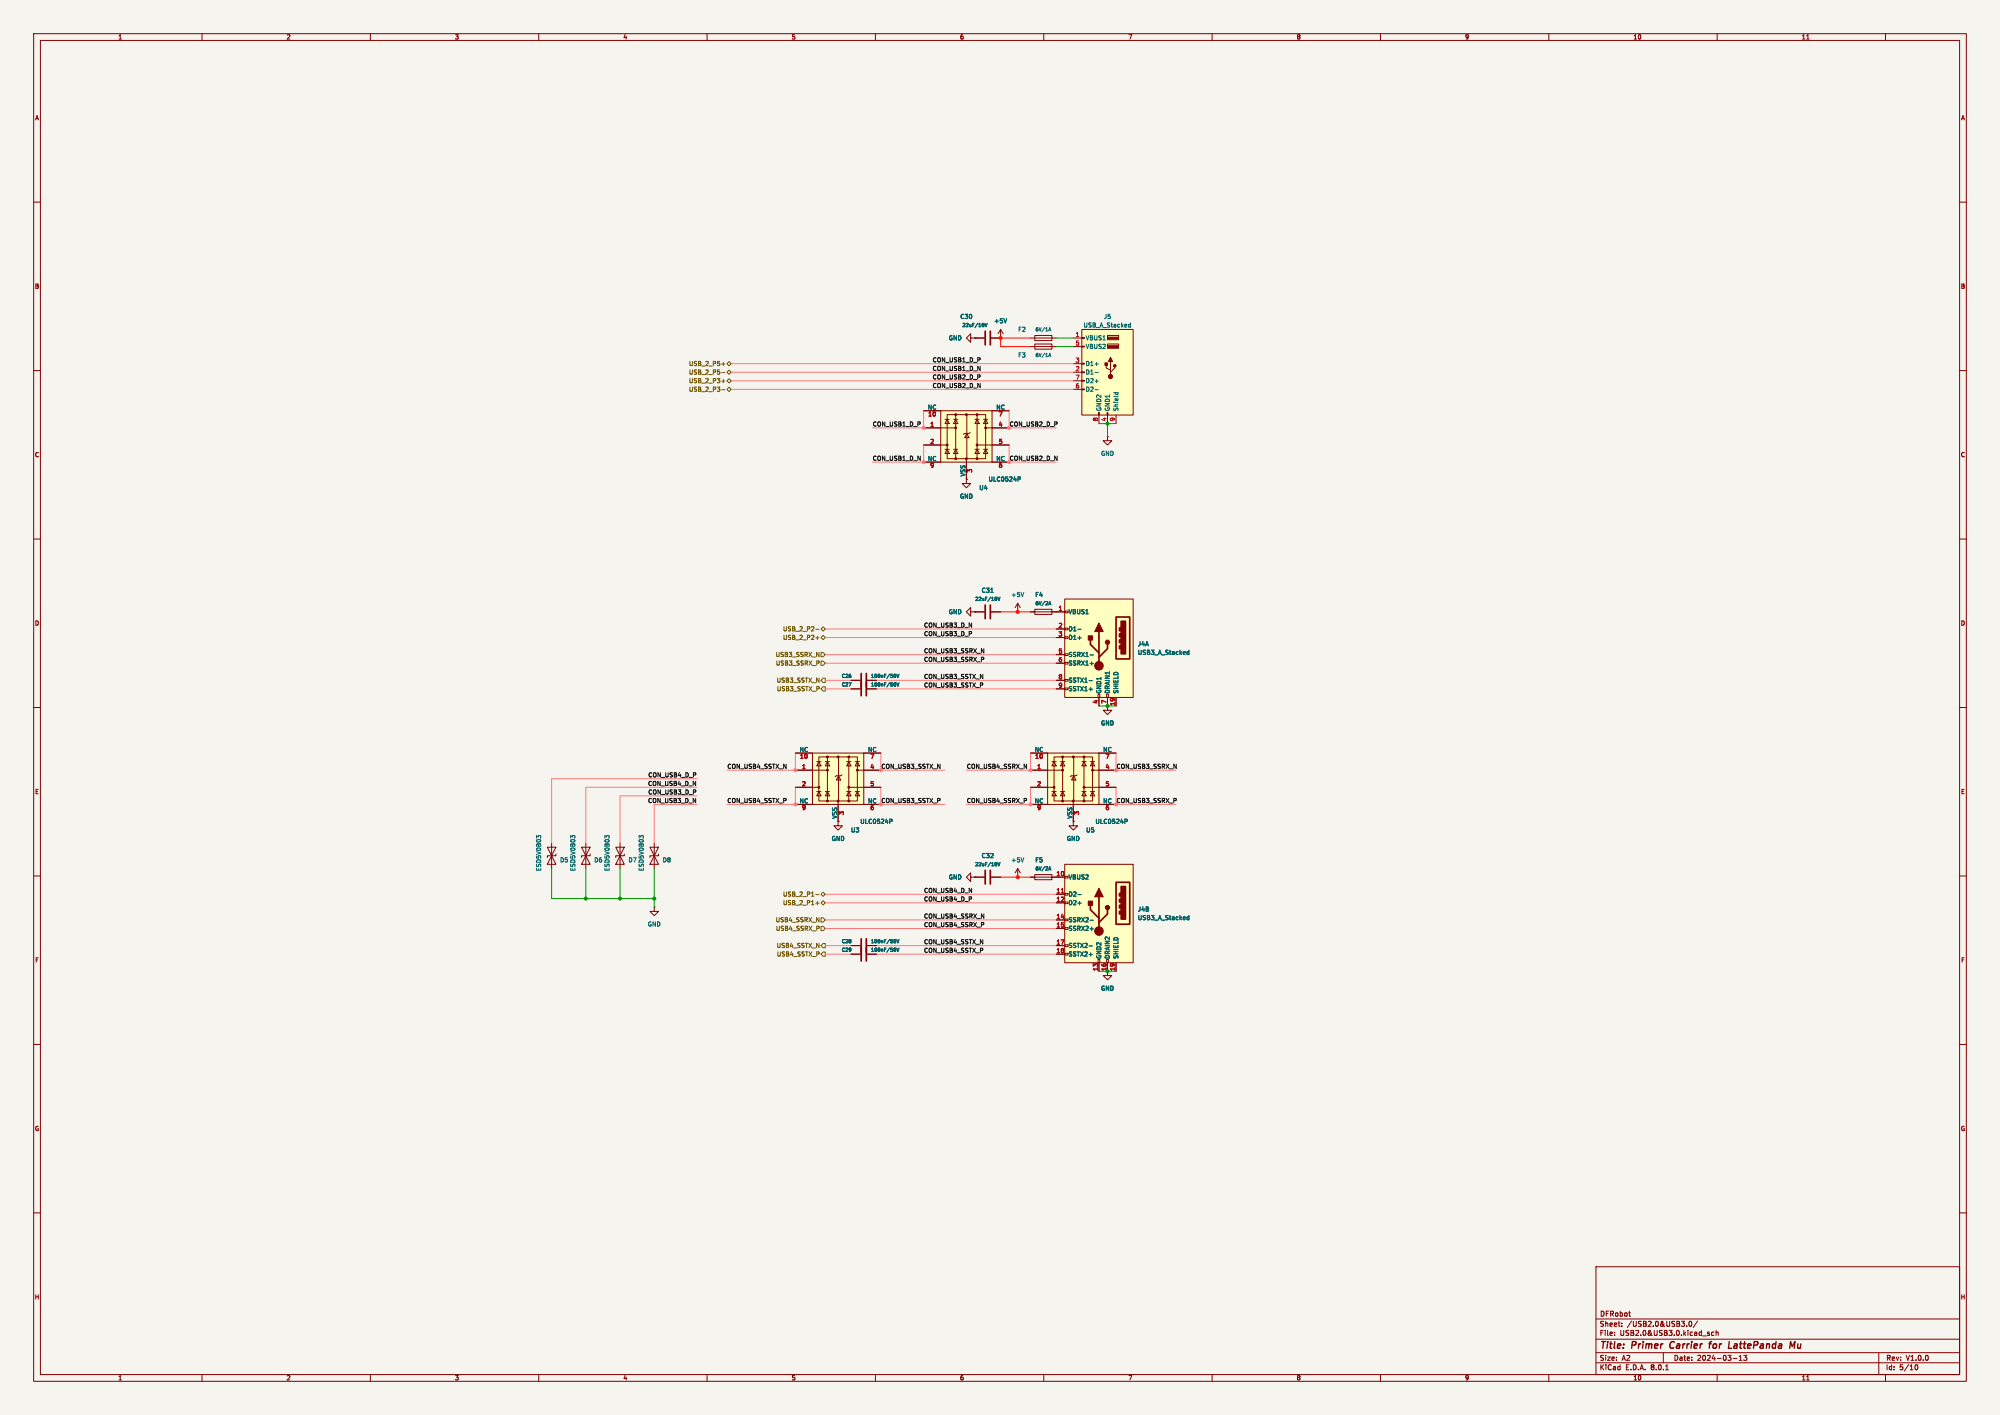
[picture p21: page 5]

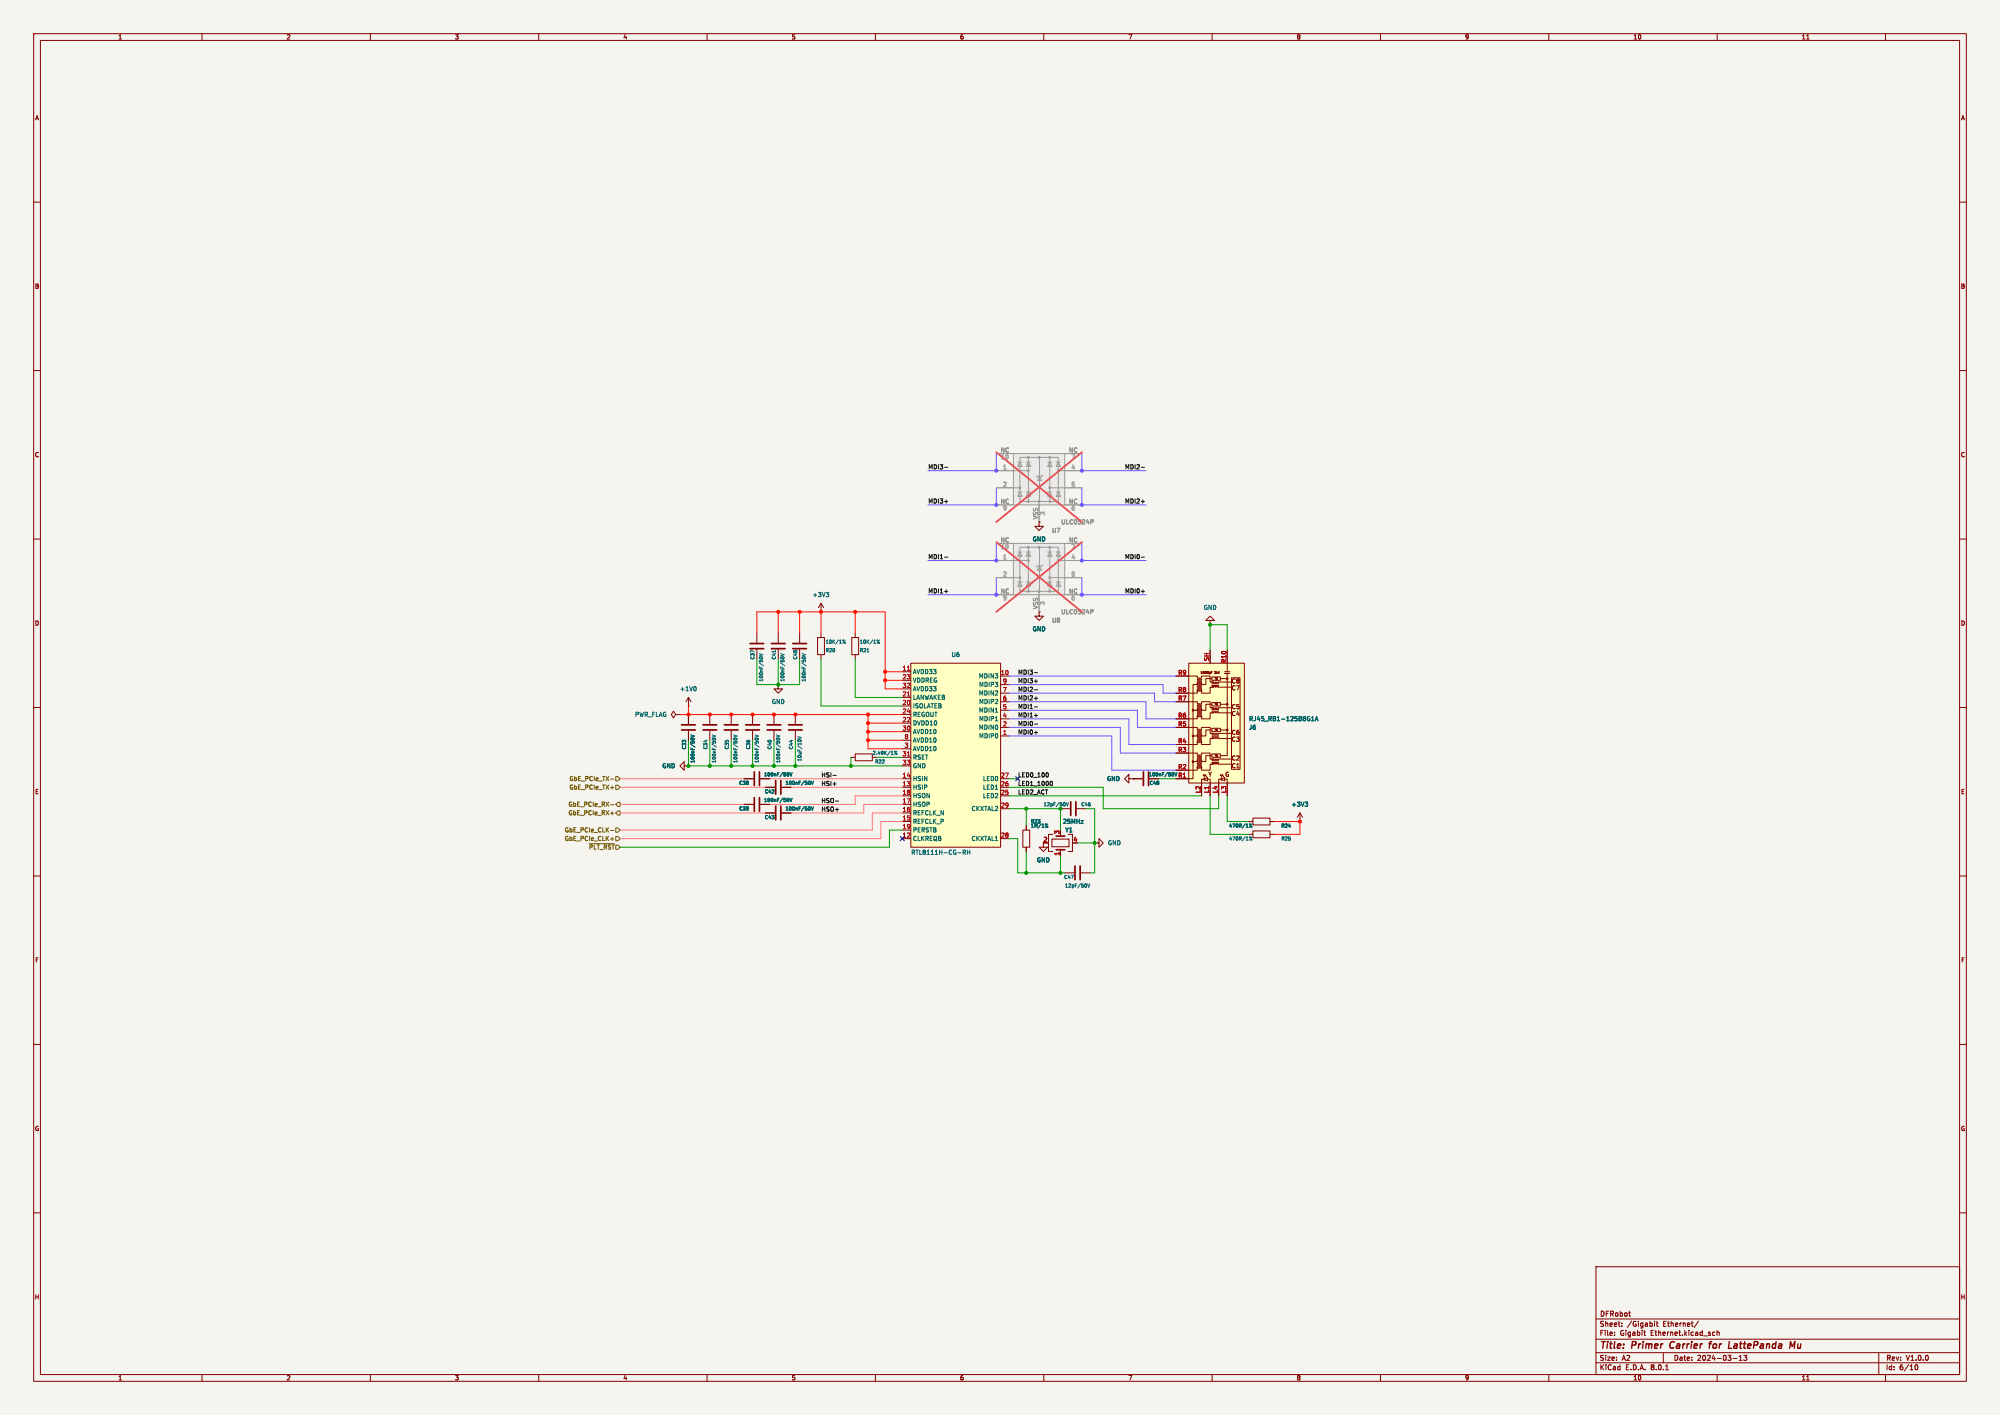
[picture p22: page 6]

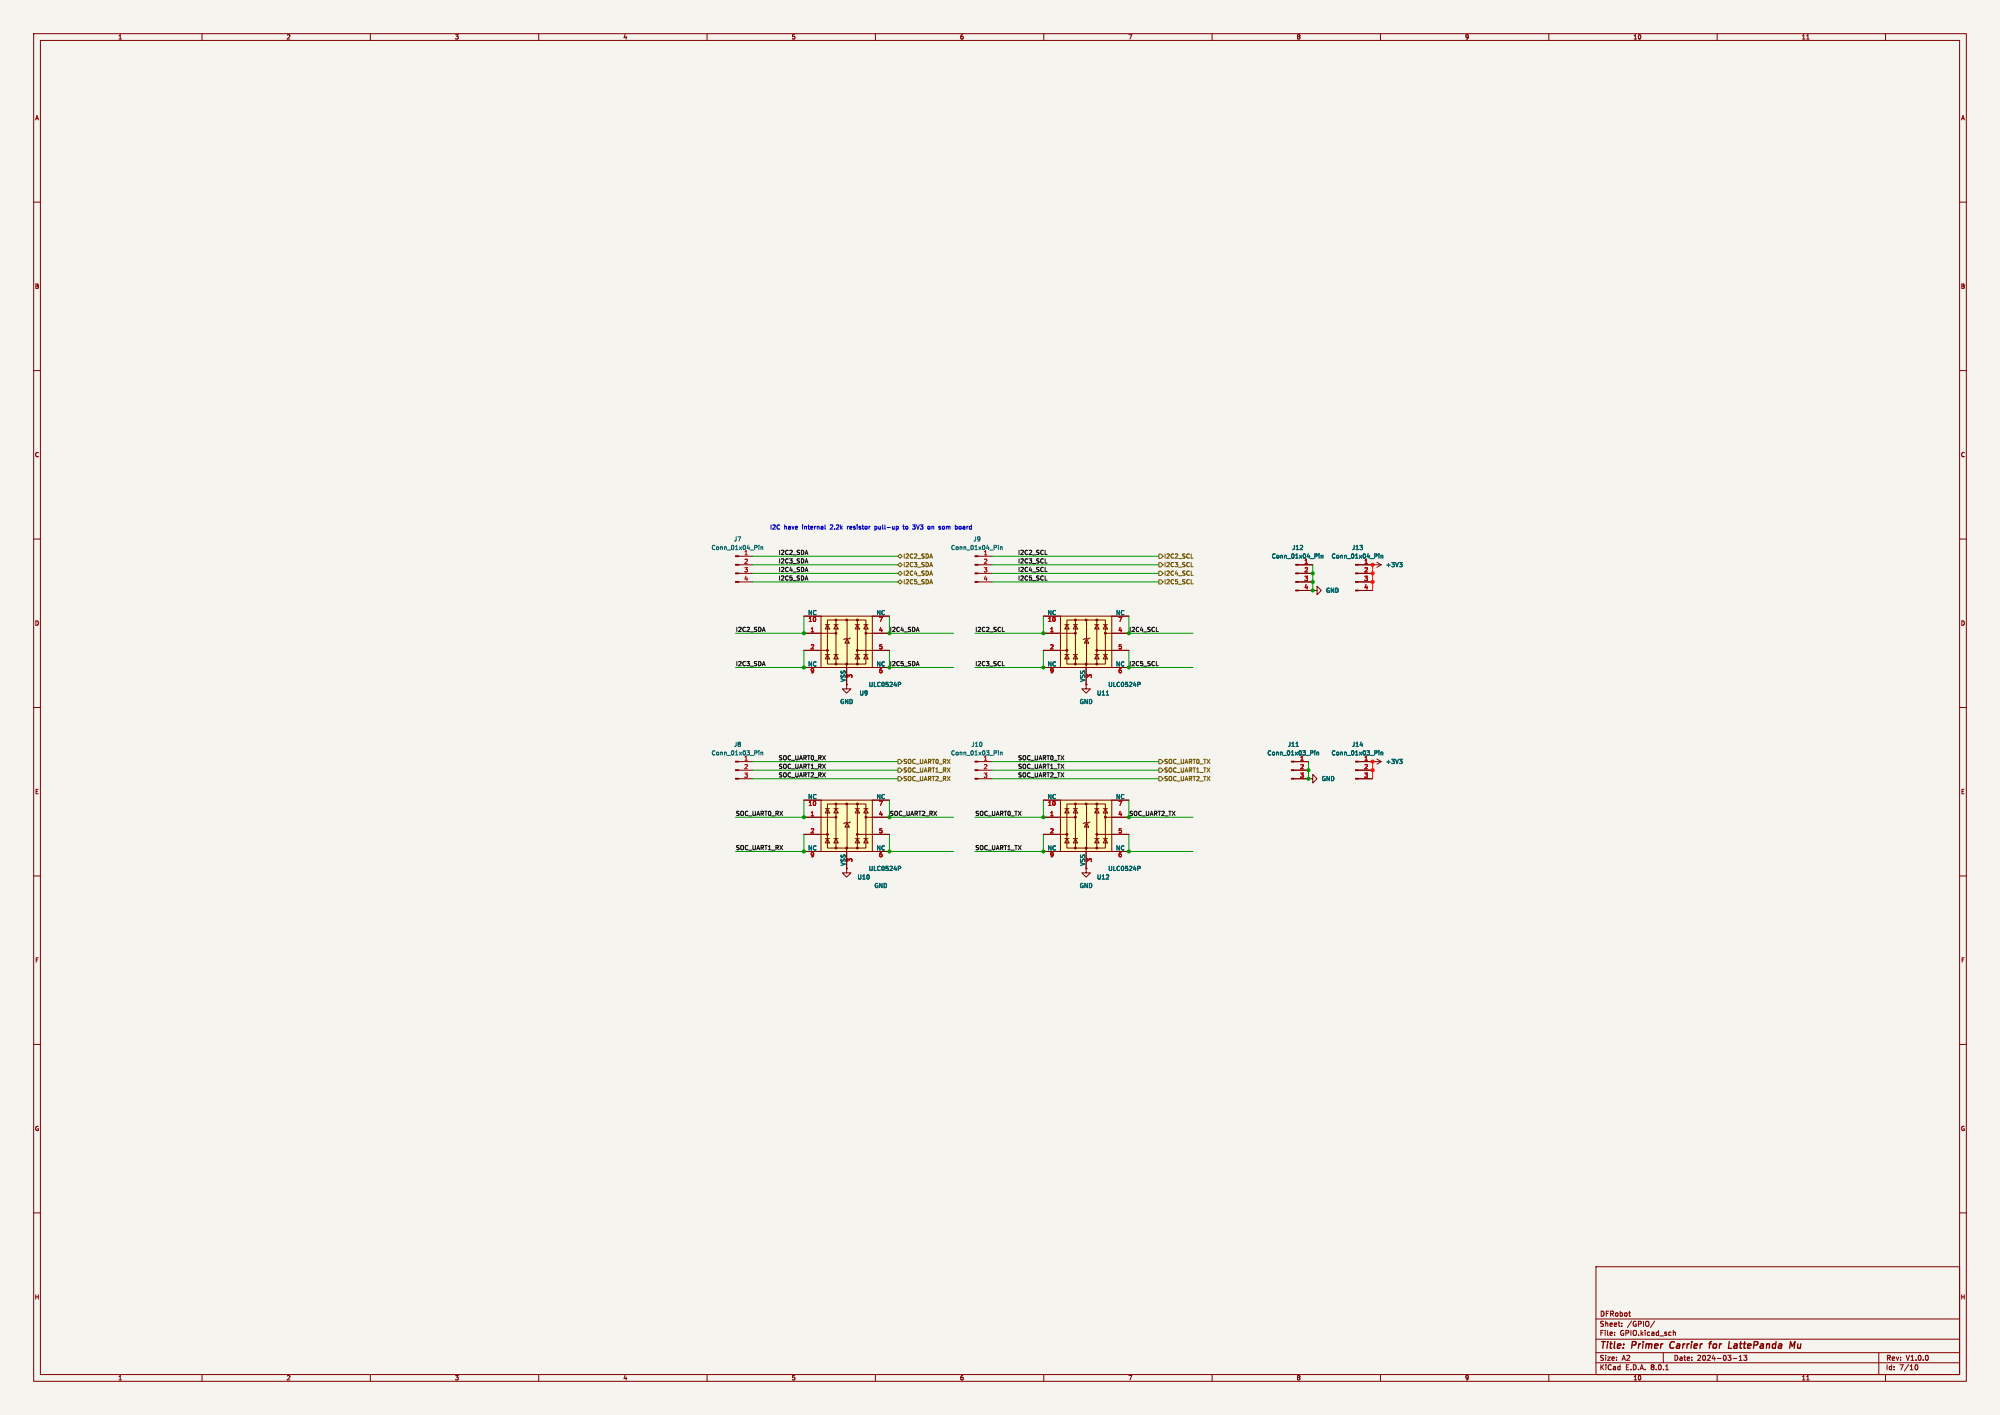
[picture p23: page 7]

File: GPIO.kicad_sch Sheet: /GPIO/ DFRobot

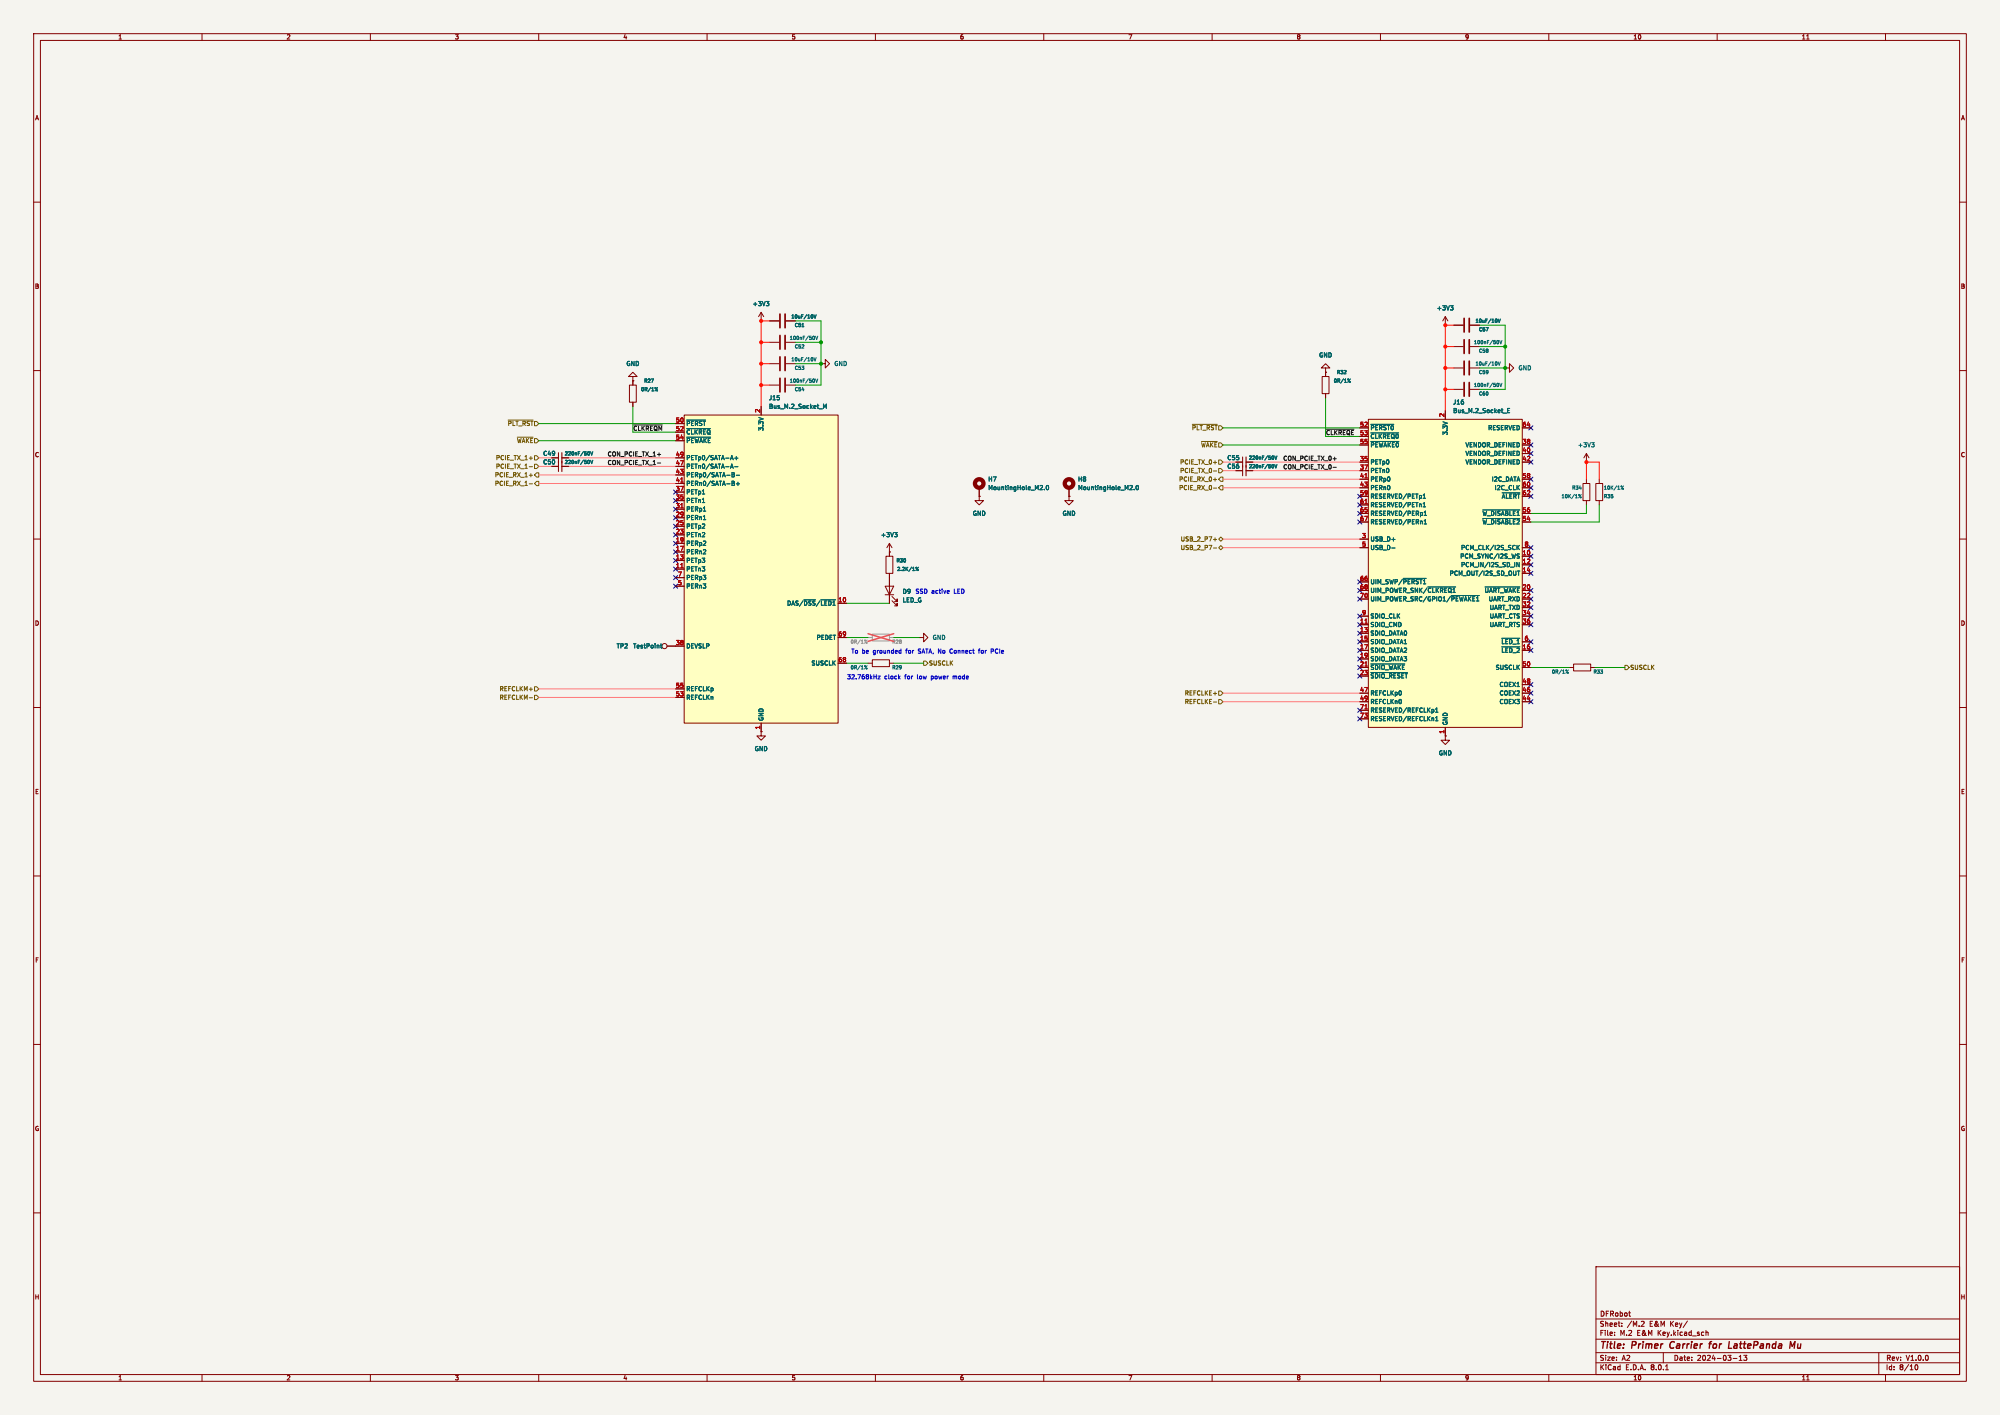
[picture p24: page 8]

2 PETn2 23 PETp2 25 PERn1 29 PERp1 31 PETn1 35 PETp1 37 DEVSLP 38 PERn0/SATA-B+ 41 PERp0/SATA-B- 43 PETn0/SATA-A- 47 PETp0/SATA-A+ 49 PERn3 5 ~{PERST} 50 ~{CLKREQ} 52 REFCLKn 53

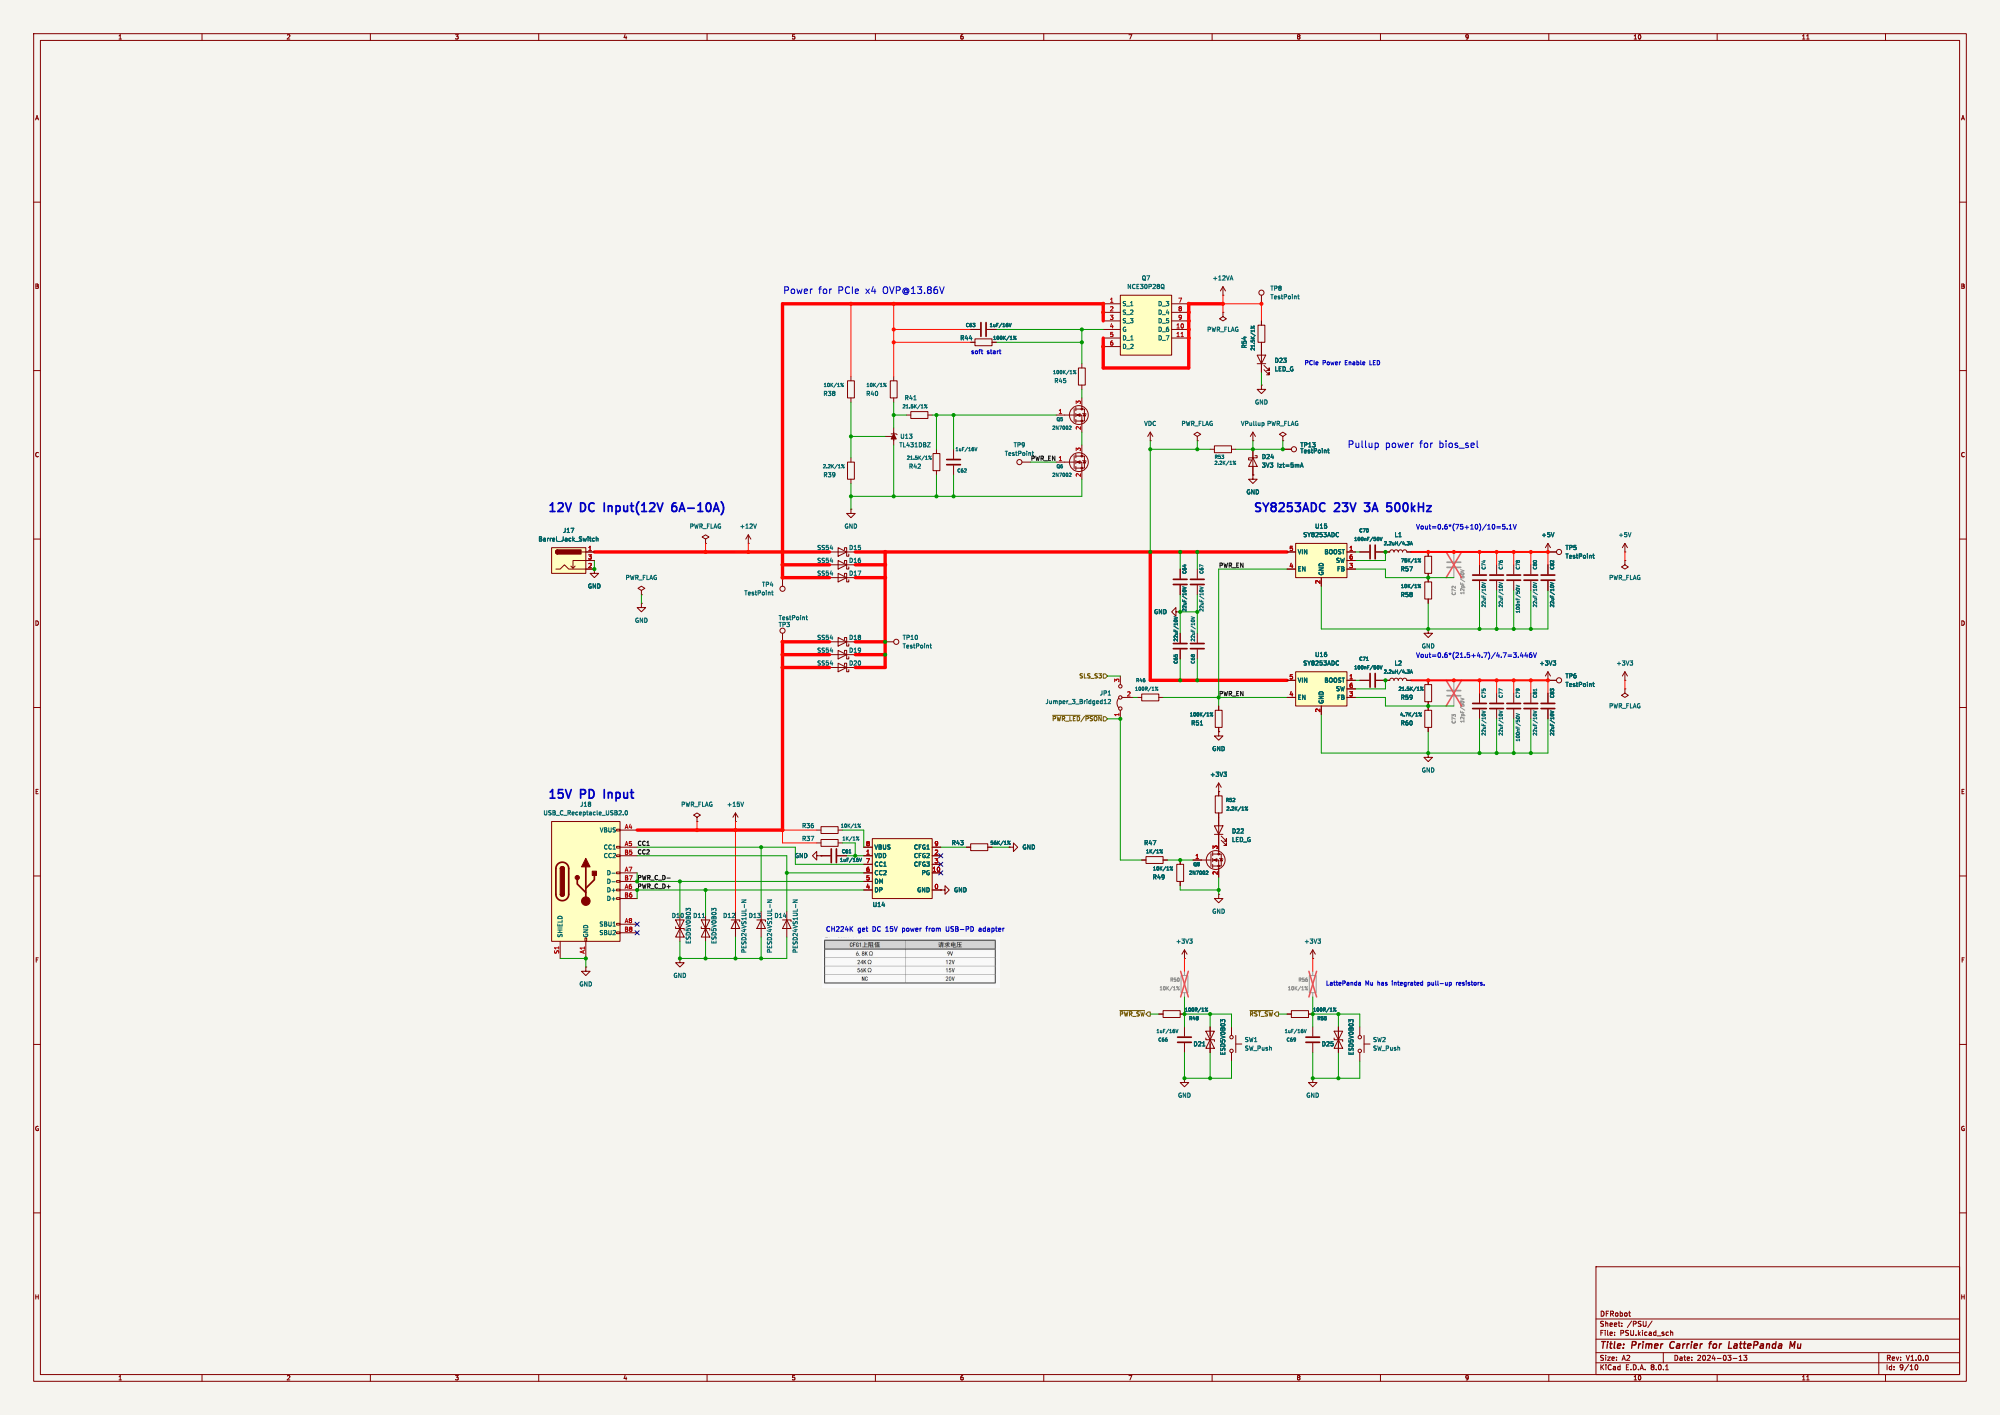
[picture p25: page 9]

Power for PCIe x4 OVP@13.86V

PCIe Power Enable LED

1 GND
File: PSU.kicad_sch Sheet: /PSU/ DFRobot C83 22uF/10V

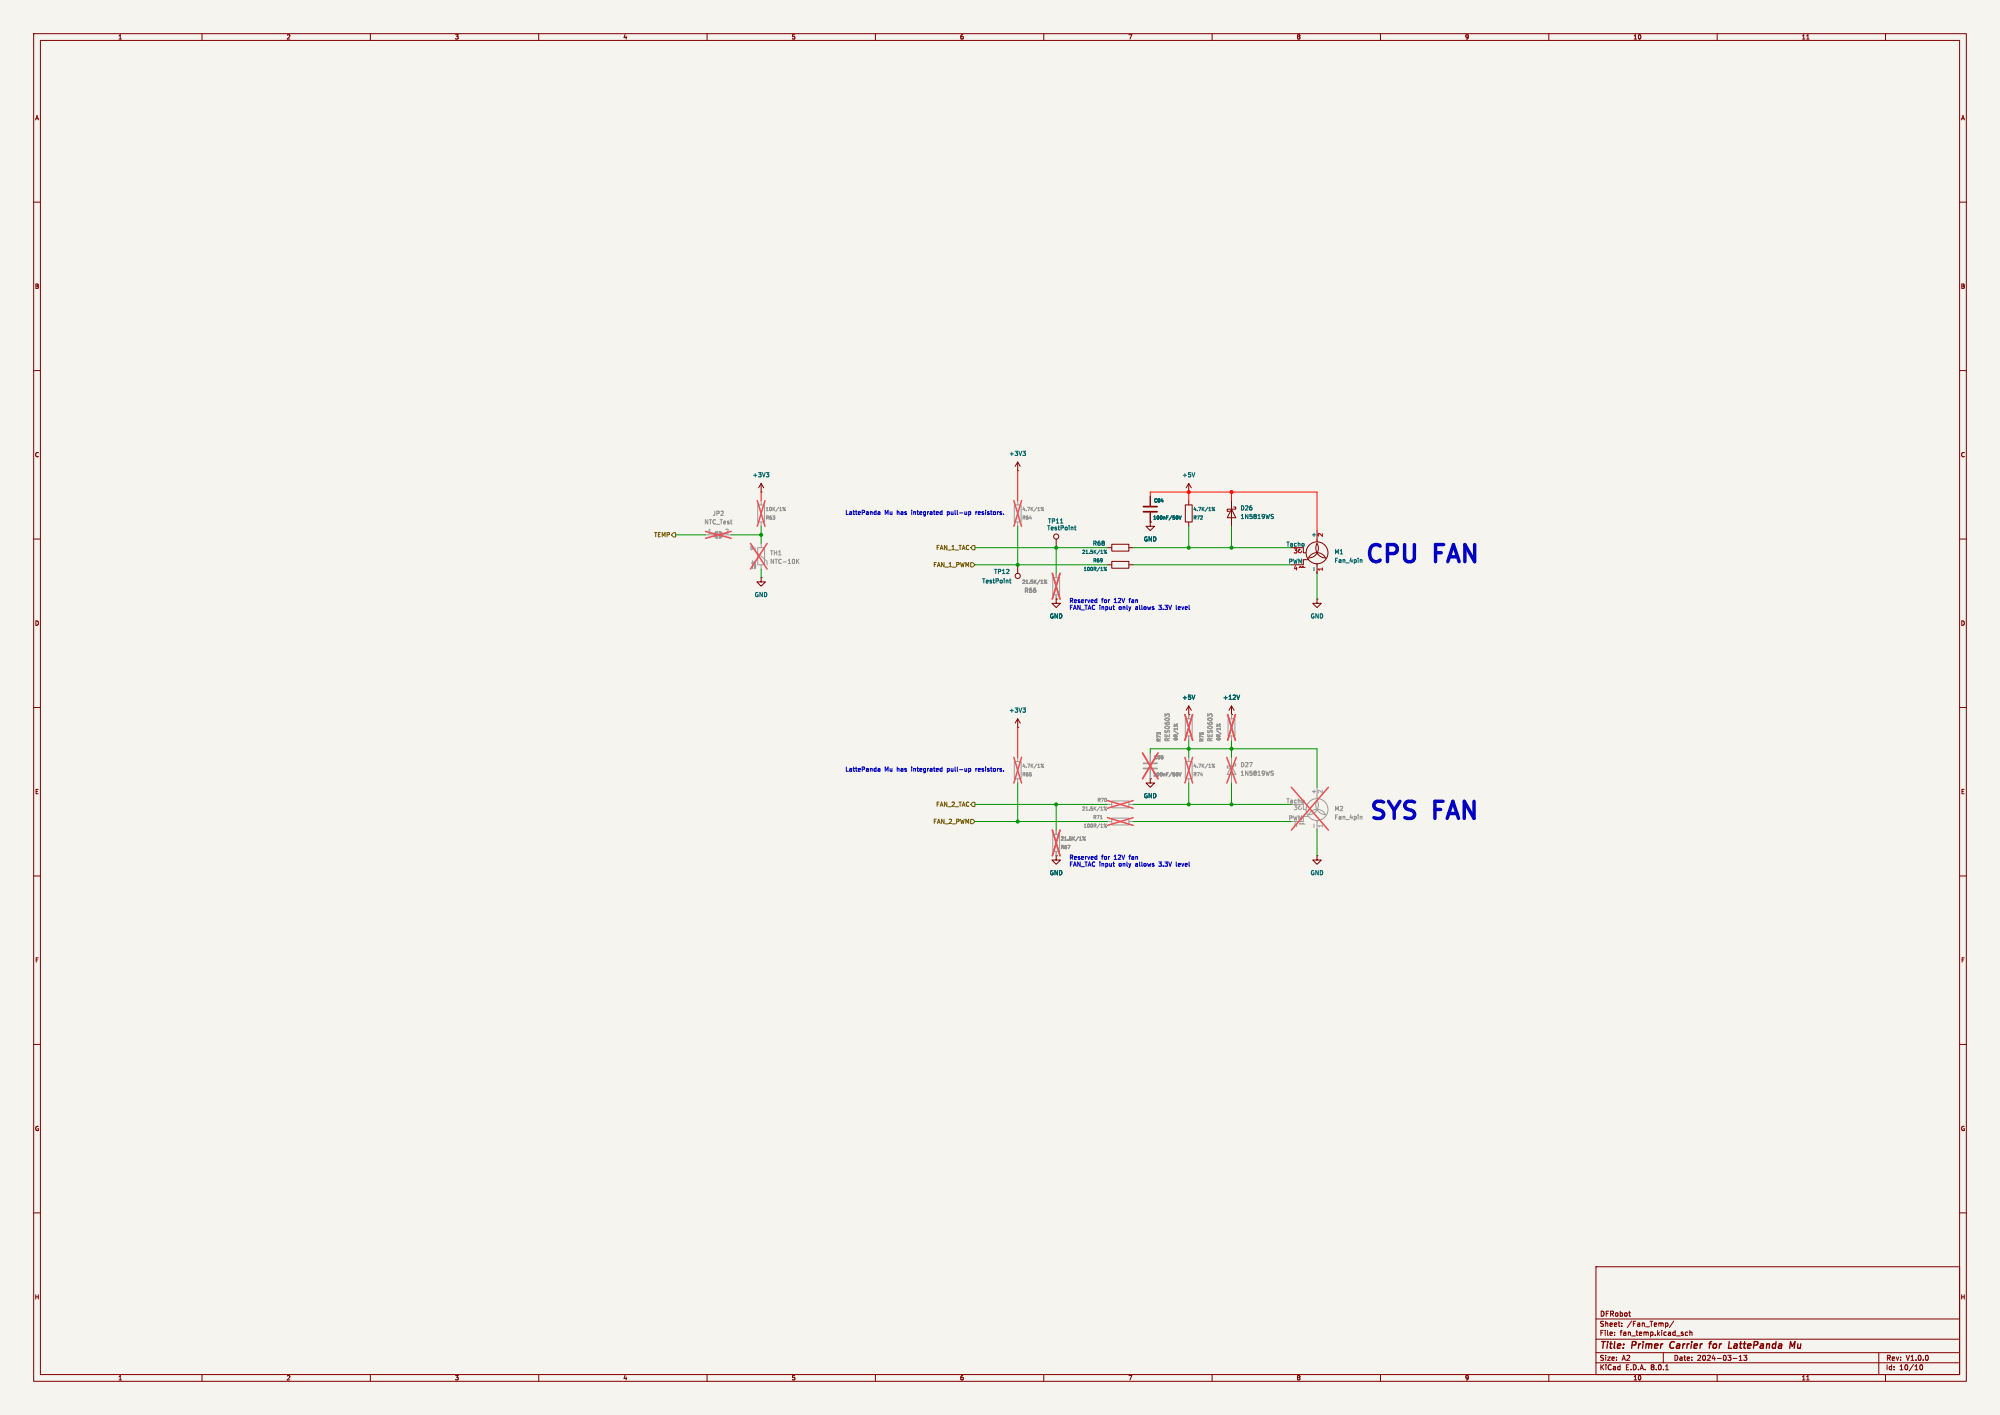
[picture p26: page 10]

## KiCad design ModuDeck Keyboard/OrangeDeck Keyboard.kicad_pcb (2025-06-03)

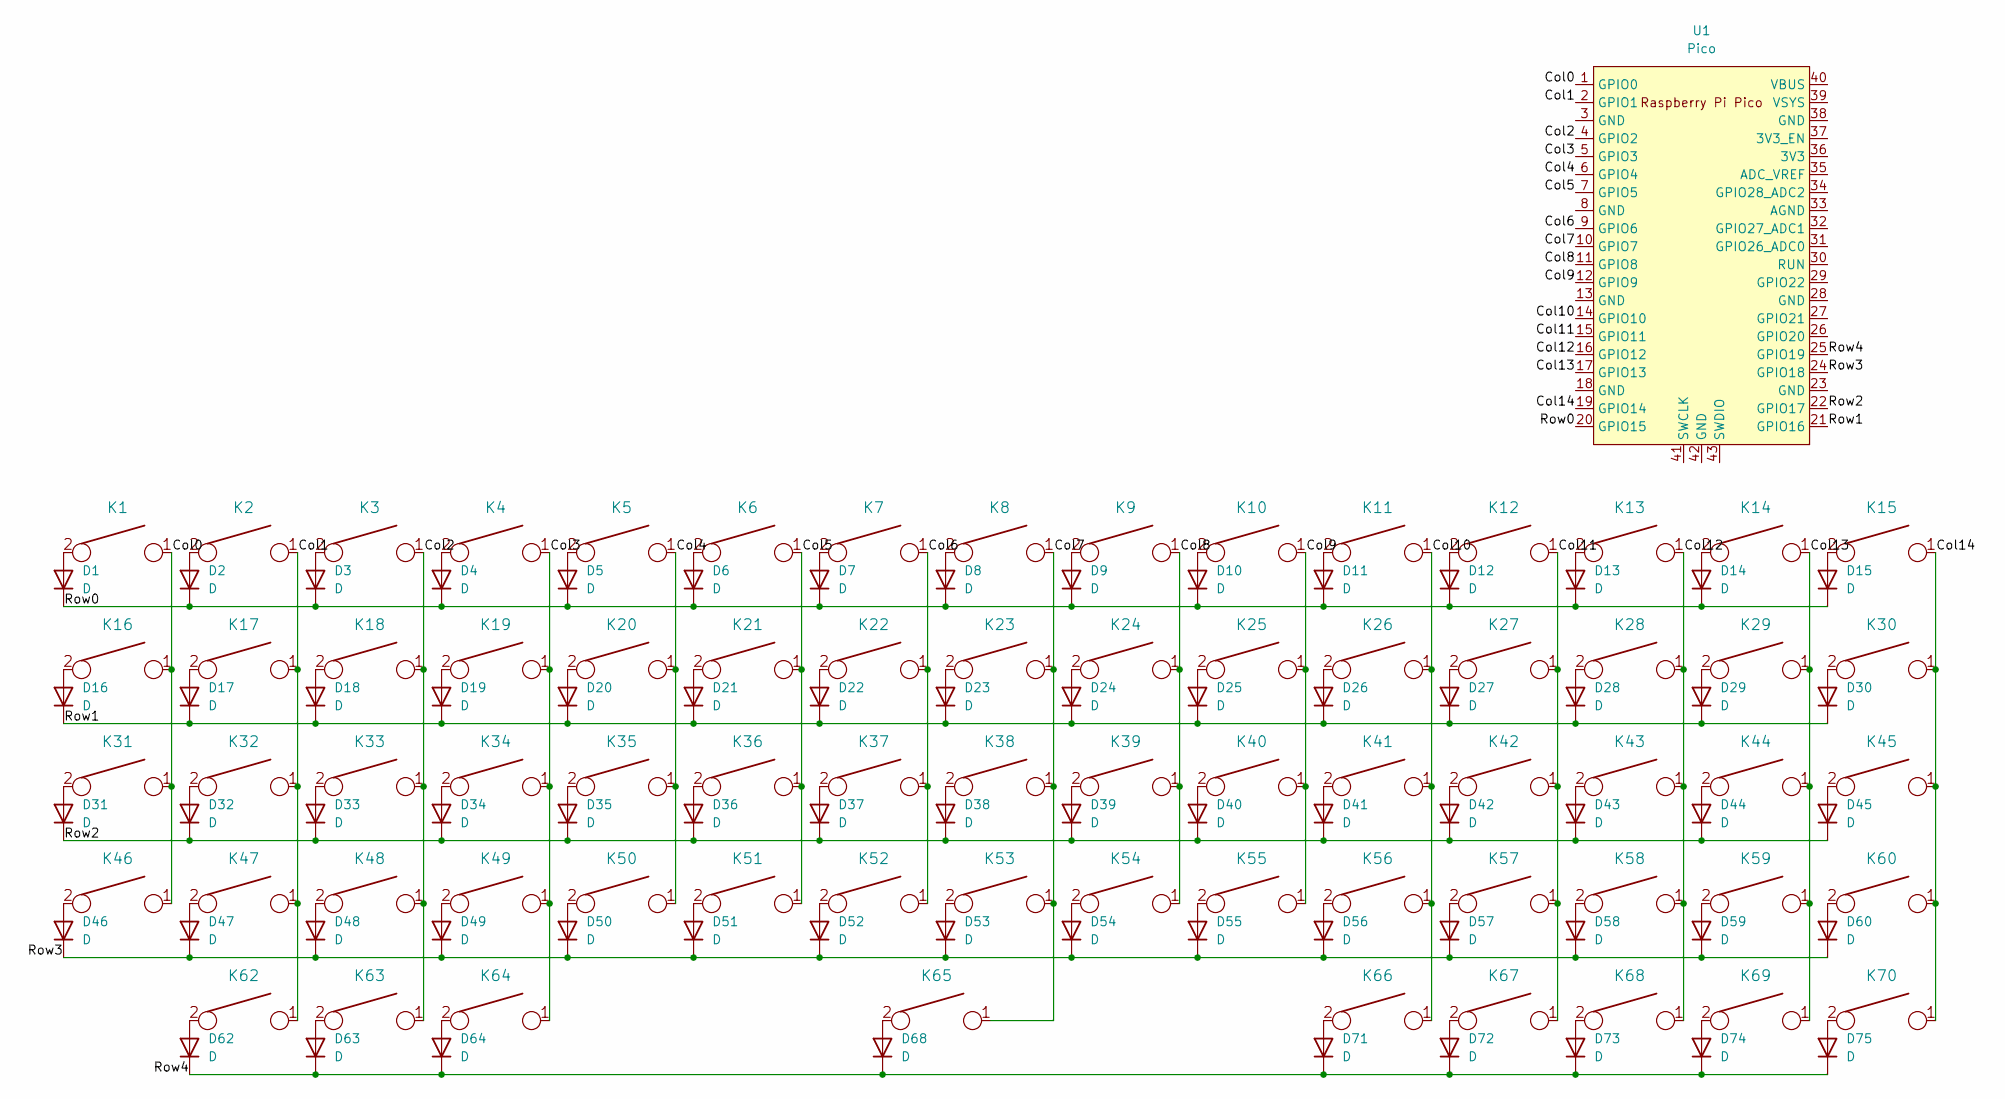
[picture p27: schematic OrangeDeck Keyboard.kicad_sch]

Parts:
D1, D2, D3, D4, D5, D6, D7, D8, D9, D10, D11, D12, D13, D14, D15, D16, D17, D18, D19, D20, D21, D22, D23, D24, D25, D26, D27, D28, D29, D30, D31, D32, D33, D34, D35, D36, D37, D38, D39, D40, D41, D42, D43, D44, D45, D46, D47, D48, D49, D50, D51, D52, D53, D54, D55, D56, D57, D58, D59, D60, D62, D63, D64, D68, D71, D72, D73, D74, D75: D; D_SOD123_axial
K1, K2, K3, K4, K5, K6, K7, K8, K9, K10, K11, K12, K13, K14, K15, K16, K17, K18, K19, K20, K21, K22, K23, K24, K25, K26, K27, K28, K29, K30, K31, K32, K33, K34, K35, K36, K37, K38, K39, K40, K41, K42, K43, K44, K45, K46, K47, K48, K49, K50, K51, K52, K53, K54, K55, K56, K57, K58, K59, K60, K62, K63, K64, K66, K67, K68, K69, K70: KEYSW; Mx_Alps_100
K65: KEYSW; Mx_Alps_625
U1: Pico; RPi_Pico_SMD_TH

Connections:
/Col0: K1.1, K16.1, K31.1, K46.1, U1.1 (GPIO0)
/Col1: K2.1, K17.1, K32.1, K47.1, K62.1, U1.2 (GPIO1)
/Col2: K3.1, K18.1, K33.1, K48.1, K63.1, U1.4 (GPIO2)
/Col3: K4.1, K19.1, K34.1, K49.1, K64.1, U1.5 (GPIO3)
/Col4: K5.1, K20.1, K35.1, K50.1, U1.6 (GPIO4)
/Col5: K6.1, K21.1, K36.1, K51.1, U1.7 (GPIO5)
/Col6: K7.1, K22.1, K37.1, K52.1, U1.9 (GPIO6)
/Col7: K8.1, K23.1, K38.1, K53.1, K65.1, U1.10 (GPIO7)
/Col8: K9.1, K24.1, K39.1, K54.1, U1.11 (GPIO8)
/Col9: K10.1, K25.1, K40.1, K55.1, U1.12 (GPIO9)
/Col10: K11.1, K26.1, K41.1, K56.1, K66.1, U1.14 (GPIO10)
/Col11: K12.1, K27.1, K42.1, K57.1, K67.1, U1.15 (GPIO11)
/Col12: K13.1, K28.1, K43.1, K58.1, K68.1, U1.16 (GPIO12)
/Col13: K14.1, K29.1, K44.1, K59.1, K69.1, U1.17 (GPIO13)
/Col14: K15.1, K30.1, K45.1, K60.1, K70.1, U1.19 (GPIO14)
/Row0: D1.1 (K), D2.1 (K), D3.1 (K), D4.1 (K), D5.1 (K), D6.1 (K), D7.1 (K), D8.1 (K), D9.1 (K), D10.1 (K), D11.1 (K), D12.1 (K), D13.1 (K), D14.1 (K), D15.1 (K), U1.20 (GPIO15)
/Row1: D16.1 (K), D17.1 (K), D18.1 (K), D19.1 (K), D20.1 (K), D21.1 (K), D22.1 (K), D23.1 (K), D24.1 (K), D25.1 (K), D26.1 (K), D27.1 (K), D28.1 (K), D29.1 (K), D30.1 (K), U1.21 (GPIO16)
/Row2: D31.1 (K), D32.1 (K), D33.1 (K), D34.1 (K), D35.1 (K), D36.1 (K), D37.1 (K), D38.1 (K), D39.1 (K), D40.1 (K), D41.1 (K), D42.1 (K), D43.1 (K), D44.1 (K), D45.1 (K), U1.22 (GPIO17)
/Row3: D46.1 (K), D47.1 (K), D48.1 (K), D49.1 (K), D50.1 (K), D51.1 (K), D52.1 (K), D53.1 (K), D54.1 (K), D55.1 (K), D56.1 (K), D57.1 (K), D58.1 (K), D59.1 (K), D60.1 (K), U1.24 (GPIO18)
/Row4: D62.1 (K), D63.1 (K), D64.1 (K), D68.1 (K), D71.1 (K), D72.1 (K), D73.1 (K), D74.1 (K), D75.1 (K), U1.25 (GPIO19)
unnamed: D1.2 (A), K1.2
unnamed: D2.2 (A), K2.2
unnamed: D3.2 (A), K3.2
unnamed: D4.2 (A), K4.2
unnamed: D5.2 (A), K5.2
unnamed: D6.2 (A), K6.2
unnamed: D7.2 (A), K7.2
unnamed: D8.2 (A), K8.2
unnamed: D9.2 (A), K9.2
unnamed: D10.2 (A), K10.2
unnamed: D11.2 (A), K11.2
unnamed: D12.2 (A), K12.2
unnamed: D13.2 (A), K13.2
unnamed: D14.2 (A), K14.2
unnamed: D15.2 (A), K15.2
unnamed: D16.2 (A), K16.2
unnamed: D17.2 (A), K17.2
unnamed: D18.2 (A), K18.2
unnamed: D19.2 (A), K19.2
unnamed: D20.2 (A), K20.2
unnamed: D21.2 (A), K21.2
unnamed: D22.2 (A), K22.2
unnamed: D23.2 (A), K23.2
unnamed: D24.2 (A), K24.2
unnamed: D25.2 (A), K25.2
unnamed: D26.2 (A), K26.2
unnamed: D27.2 (A), K27.2
unnamed: D28.2 (A), K28.2
unnamed: D29.2 (A), K29.2
unnamed: D30.2 (A), K30.2
unnamed: D31.2 (A), K31.2
unnamed: D32.2 (A), K32.2
unnamed: D33.2 (A), K33.2
unnamed: D34.2 (A), K34.2
unnamed: D35.2 (A), K35.2
unnamed: D36.2 (A), K36.2
unnamed: D37.2 (A), K37.2
unnamed: D38.2 (A), K38.2
unnamed: D39.2 (A), K39.2
unnamed: D40.2 (A), K40.2
unnamed: D41.2 (A), K41.2
unnamed: D42.2 (A), K42.2
unnamed: D43.2 (A), K43.2
unnamed: D44.2 (A), K44.2
unnamed: D45.2 (A), K45.2
unnamed: D46.2 (A), K46.2
unnamed: D47.2 (A), K47.2
unnamed: D48.2 (A), K48.2
unnamed: D49.2 (A), K49.2
unnamed: D50.2 (A), K50.2
unnamed: D51.2 (A), K51.2
unnamed: D52.2 (A), K52.2
unnamed: D53.2 (A), K53.2
unnamed: D54.2 (A), K54.2
unnamed: D55.2 (A), K55.2
unnamed: D56.2 (A), K56.2
unnamed: D57.2 (A), K57.2
unnamed: D58.2 (A), K58.2
unnamed: D59.2 (A), K59.2
unnamed: D60.2 (A), K60.2
unnamed: D62.2 (A), K62.2
unnamed: D63.2 (A), K63.2
unnamed: D64.2 (A), K64.2
unnamed: D68.2 (A), K65.2
unnamed: D71.2 (A), K66.2
unnamed: D72.2 (A), K67.2
unnamed: D73.2 (A), K68.2
unnamed: D74.2 (A), K69.2
unnamed: D75.2 (A), K70.2

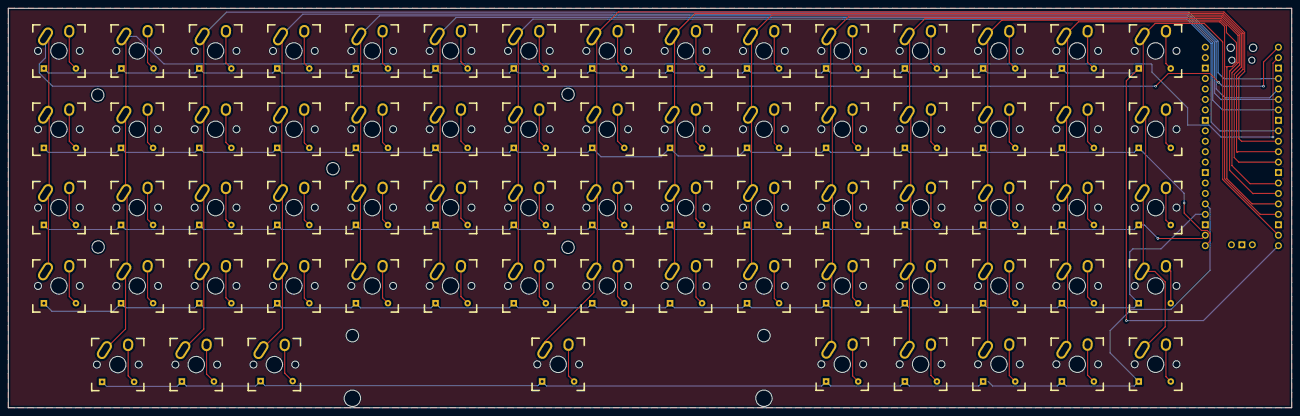
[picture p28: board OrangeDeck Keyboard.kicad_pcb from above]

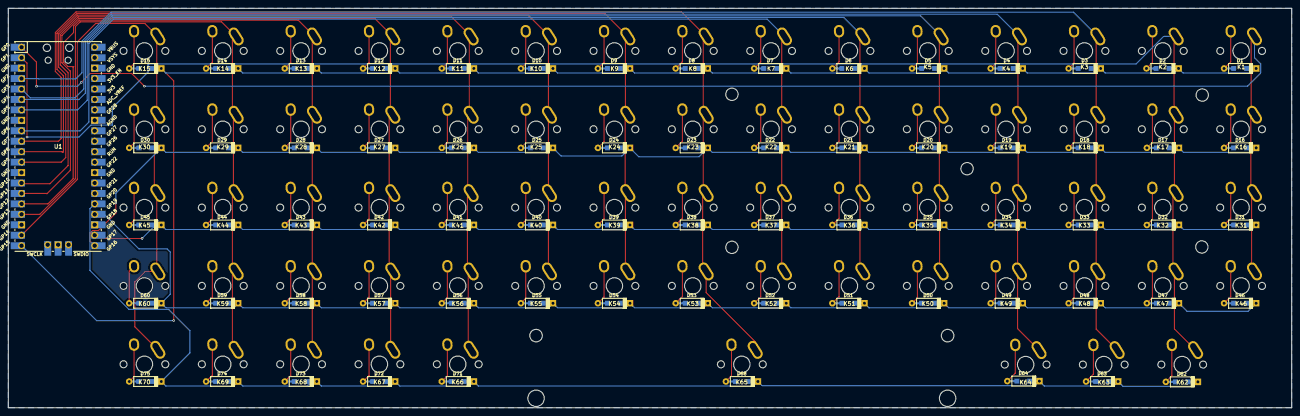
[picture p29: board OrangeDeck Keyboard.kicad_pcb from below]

Board: 2 copper layers, 312.1 x 97.1 mm, 139 parts (70 on the bottom side), 89 nets.

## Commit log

2025-06-03 adding all my work lol
    [Back Case left.stl, Back Case right.stl, Back case.stl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]
2025-06-06 Finished battery guides
2025-06-07 fixed mounting
    [Panda Compute Main.stl, Rpi zero compute.stl]
2025-06-12 Update Rpi zero compute.stl
    [Rpi zero compute.stl]
2025-06-13 fixing ports
    [Case Right.stl, Case left.stl, Rpi zero compute.stl]
2025-06-15 edited stls
    [Back Case left.stl, Battery module.stl, Case Right.stl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]
2025-06-16 Update Case Right.stl
    [Case Right.stl]
